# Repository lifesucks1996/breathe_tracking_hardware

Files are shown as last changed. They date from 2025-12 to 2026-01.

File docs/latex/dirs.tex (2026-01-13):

\doxysection{Directories}
\begin{DoxyCompactList}
\item \contentsline{section}{Hola\+Mundo\+IBeacon }{\pageref{dir_2c5f92dce44fa62186c079fa2c237f16}}{}
\begin{DoxyCompactList}
\item \contentsline{section}{Emisora\+BLE.\+h }{\pageref{_emisora_b_l_e_8h}}{}
\item \contentsline{section}{LED.\+h }{\pageref{_l_e_d_8h}}{}
\item \contentsline{section}{Medidor.\+h }{\pageref{_medidor_8h}}{}
\item \contentsline{section}{Publicador.\+h }{\pageref{_publicador_8h}}{}
\item \contentsline{section}{Puerto\+Serie.\+h }{\pageref{_puerto_serie_8h}}{}
\item \contentsline{section}{Servicio\+En\+Emisora.\+h }{\pageref{_servicio_en_emisora_8h}}{}
\end{DoxyCompactList}
\item \contentsline{section}{src }{\pageref{dir_68267d1309a1af8e8297ef4c3efbcdba}}{}
\begin{DoxyCompactList}
\item \contentsline{section}{Hola\+Mundo\+IBeacon }{\pageref{dir_2c5f92dce44fa62186c079fa2c237f16}}{}
\begin{DoxyCompactList}
\item \contentsline{section}{Emisora\+BLE.\+h }{\pageref{_emisora_b_l_e_8h}}{}
\item \contentsline{section}{LED.\+h }{\pageref{_l_e_d_8h}}{}
\item \contentsline{section}{Medidor.\+h }{\pageref{_medidor_8h}}{}
\item \contentsline{section}{Publicador.\+h }{\pageref{_publicador_8h}}{}
\item \contentsline{section}{Puerto\+Serie.\+h }{\pageref{_puerto_serie_8h}}{}
\item \contentsline{section}{Servicio\+En\+Emisora.\+h }{\pageref{_servicio_en_emisora_8h}}{}
\end{DoxyCompactList}
\end{DoxyCompactList}
\end{DoxyCompactList}

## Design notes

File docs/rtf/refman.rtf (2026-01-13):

Breathe Traking

AUTHOR
Version 1.0

Table of Contents

Table of contents

Directory Hierarchy
Directories

HolaMundoIBeacon pagenum
EmisoraBLE.h pagenum
LED.h pagenum
Medidor.h pagenum
Publicador.h pagenum
PuertoSerie.h pagenum
ServicioEnEmisora.h pagenum

src pagenum
HolaMundoIBeacon pagenum
EmisoraBLE.h pagenum
LED.h pagenum
Medidor.h pagenum
Publicador.h pagenum
PuertoSerie.h pagenum
ServicioEnEmisora.h pagenum

Class Index
Class List
Here are the classes, structs, unions and interfaces with brief descriptions:
ServicioEnEmisora::Caracteristica (Representa una Característica GATT dentro de un servicio ) pagenum
EmisoraBLE (Clase que abstrae las funciones de Bluefruit para actuar como periférico BLE ) pagenum
LED (Clase para gestionar un diodo LED conectado a un pin GPIO ) pagenum
Medidor (Se encarga de la adquisición y procesamiento de datos ambientales ) pagenum
Publicador (Gestiona la lógica de empaquetado y emisión de datos de sensores ) pagenum
PuertoSerie (Clase de abstracción para la comunicación serie ) pagenum
ServicioEnEmisora (Clase que representa un Servicio GATT de Bluetooth ) pagenum

File Index
File List
Here is a list of all files with brief descriptions:
src/HolaMundoIBeacon/EmisoraBLE.h (Clase para gestionar la publicidad y conexión de una emisora Bluetooth Low Energy (BLE) ) pagenum
src/HolaMundoIBeacon/LED.h (Clase para el control de un LED y funciones auxiliares de tiempo ) pagenum
src/HolaMundoIBeacon/Medidor.h (Clase para la gestión de sensores analógicos y simulados ) pagenum
src/HolaMundoIBeacon/Publicador.h (Clase para la publicación de mediciones ambientales mediante beacons BLE ) pagenum
src/HolaMundoIBeacon/PuertoSerie.h (Clase para gestionar la comunicación serie del microcontrolador ) pagenum
src/HolaMundoIBeacon/ServicioEnEmisora.h (Gestión de Servicios y Características GATT para BLE ) pagenum

Directory Documentation
src/HolaMundoIBeacon Directory Reference
AAAAAAABQHAAAAAAABQHFiles
file EmisoraBLE.h
Clase para gestionar la publicidad y conexión de una emisora Bluetooth Low Energy (BLE).
file LED.h
Clase para el control de un LED y funciones auxiliares de tiempo.
file Medidor.h
Clase para la gestión de sensores analógicos y simulados.
file Publicador.h
Clase para la publicación de mediciones ambientales mediante beacons BLE.
file PuertoSerie.h
Clase para gestionar la comunicación serie del microcontrolador.
file ServicioEnEmisora.h
Gestión de Servicios y Características GATT para BLE.

src Directory Reference
AAAAAAABQIAAAAAAABQIDirectories
directory HolaMundoIBeacon
Class Documentation
ServicioEnEmisora::Caracteristica Class Reference
AAAAAAAAJGAAAAAAAAJG
Representa una Característica GATT dentro de un servicio.
#include <ServicioEnEmisora.h>

Public Member Functions
Caracteristica (const char *nombreCaracteristica_)
Constructor básico de característica.

Caracteristica (const char *nombreCaracteristica_, uint8_t props, SecureMode_t permisoRead, SecureMode_t permisoWrite, uint8_t tam)
Constructor completo de característica.

void asignarPropiedadesPermisosYTamanyoDatos (uint8_t props, SecureMode_t permisoRead, SecureMode_t permisoWrite, uint8_t tam)
Configura las propiedades, permisos y tamaño de la característica.

uint16_t escribirDatos (const char *str)
Escribe datos de forma local en la característica.

uint16_t notificarDatos (const char *str)
Envía una notificación a los clientes suscritos.

void instalarCallbackCaracteristicaEscrita (CallbackCaracteristicaEscrita cb)
Configura el callback de escritura.

void activar ()
Activa la característica para que sea visible por el servicio.

Private Member Functions
void asignarPropiedades (uint8_t props)
void asignarPermisos (SecureMode_t permisoRead, SecureMode_t permisoWrite)
void asignarTamanyoDatos (uint8_t tam)
Private Attributes
uint8_t uuidCaracteristica [16] = { '0','1','2','3','4','5','6','7','8','9','A','B','C','D','E','F' }
BLECharacteristic laCaracteristica

Detailed Description
Representa una Característica GATT dentro de un servicio.
Definition at line 71 of file ServicioEnEmisora.h.

AAAAAAABQEAAAAAAABQEConstructor & Destructor Documentation
ServicioEnEmisora::Caracteristica::Caracteristica (const char * nombreCaracteristica_)
AAAAAAABJGAAAAAAABJG
Constructor básico de característica.

Parameters
nombreCaracteristica_ | UUID de la característica como string.
Definition at line 81 of file ServicioEnEmisora.h. ServicioEnEmisora::Caracteristica::Caracteristica (const char * nombreCaracteristica_, uint8_t props, SecureMode_t permisoRead, SecureMode_t permisoWrite, uint8_t tam)
AAAAAAABKFAAAAAAABKF
Constructor completo de característica.

Parameters
nombreCaracteristica_ | UUID en formato string.
props | Propiedades (Read, Write, Notify...).
permisoRead | Permisos de seguridad para lectura.
permisoWrite | Permisos de seguridad para escritura.
tam | Tamaño máximo de los datos en bytes.
Definition at line 93 of file ServicioEnEmisora.h.
AAAAAAABQFAAAAAAABQFMember Function Documentation
void ServicioEnEmisora::Caracteristica::activar ()
AAAAAAABMQAAAAAAABMQ
Activa la característica para que sea visible por el servicio.
Definition at line 148 of file ServicioEnEmisora.h.
void ServicioEnEmisora::Caracteristica::asignarPermisos (SecureMode_t permisoRead, SecureMode_t permisoWrite)[private]
AAAAAAABKUAAAAAAABKU
Definition at line 105 of file ServicioEnEmisora.h.
void ServicioEnEmisora::Caracteristica::asignarPropiedades (uint8_t props)[private]
AAAAAAABKSAAAAAAABKS
Definition at line 104 of file ServicioEnEmisora.h.
void ServicioEnEmisora::Caracteristica::asignarPropiedadesPermisosYTamanyoDatos (uint8_t props, SecureMode_t permisoRead, SecureMode_t permisoWrite, uint8_t tam)
AAAAAAABKNAAAAAAABKN
Configura las propiedades, permisos y tamaño de la característica.
Definition at line 114 of file ServicioEnEmisora.h.
void ServicioEnEmisora::Caracteristica::asignarTamanyoDatos (uint8_t tam)[private]
AAAAAAABKYAAAAAAABKY
Definition at line 108 of file ServicioEnEmisora.h.
uint16_t ServicioEnEmisora::Caracteristica::escribirDatos (const char * str)
AAAAAAABLTAAAAAAABLT
Escribe datos de forma local en la característica.

Parameters
str | Cadena a escribir.
Returns Número de bytes escritos.
Definition at line 128 of file ServicioEnEmisora.h.
void ServicioEnEmisora::Caracteristica::instalarCallbackCaracteristicaEscrita (CallbackCaracteristicaEscrita cb)
AAAAAAABMIAAAAAAABMI
Configura el callback de escritura.

Parameters
cb | Función a ejecutar cuando un cliente escribe datos.
Definition at line 141 of file ServicioEnEmisora.h. uint16_t ServicioEnEmisora::Caracteristica::notificarDatos (const char * str)
AAAAAAABMBAAAAAAABMB
Envía una notificación a los clientes suscritos.

Parameters
str | Datos a notificar.
Returns Resultado de la operación de notificación.
Definition at line 135 of file ServicioEnEmisora.h.

AAAAAAABQGAAAAAAABQGMember Data Documentation
BLECharacteristic ServicioEnEmisora::Caracteristica::laCaracteristica[private]
AAAAAAABJLAAAAAAABJL
Definition at line 74 of file ServicioEnEmisora.h.
uint8_t ServicioEnEmisora::Caracteristica::uuidCaracteristica[16] = { '0','1','2','3','4','5','6','7','8','9','A','B','C','D','E','F' }[private]
AAAAAAABJJAAAAAAABJJ
Definition at line 73 of file ServicioEnEmisora.h.

The documentation for this class was generated from the following file:
src/HolaMundoIBeacon/ServicioEnEmisora.h

EmisoraBLE Class Reference
AAAAAAAAAWAAAAAAAAAW
Clase que abstrae las funciones de Bluefruit para actuar como periférico BLE.
#include <EmisoraBLE.h>

Public Types
using CallbackConexionEstablecida = void ( uint16_t connHandle )
Alias para el callback de conexión establecida.

using CallbackConexionTerminada = void ( uint16_t connHandle, uint8_t reason)
Alias para el callback de conexión terminada.

Public Member Functions
EmisoraBLE (const char *nombreEmisora_, const uint16_t fabricanteID_, const int8_t txPower_)
Constructor de la clase EmisoraBLE.

void encenderEmisora ()
Inicializa el hardware Bluefruit y detiene anuncios previos.

void encenderEmisora (CallbackConexionEstablecida cbce, CallbackConexionTerminada cbct)
Enciende la emisora y configura los callbacks de conexión.

void detenerAnuncio ()
Detiene la publicidad (advertising) si está activa.

bool estaAnunciando ()
Comprueba si la emisora está emitiendo anuncios actualmente.

void emitirAnuncioIBeacon (uint8_t *beaconUUID, int16_t major, int16_t minor, uint8_t rssi)
Configura y emite un anuncio estándar iBeacon.

void emitirAnuncioIBeaconLibre (const char *carga, const uint8_t tamanyoCarga)
Emite un anuncio iBeacon con una carga de datos personalizada.

void emitirDatosMultiples (const uint8_t *datos, const uint8_t tamanyoDatos)
Emite datos múltiples en la carga de fabricante.

bool anyadirServicio (ServicioEnEmisora &servicio)
Añade un servicio a la emisora.

bool anyadirServicioConSusCaracteristicas (ServicioEnEmisora &servicio)
Añade un servicio y sus características.

template<typename ... T> bool anyadirServicioConSusCaracteristicas (ServicioEnEmisora &servicio, ServicioEnEmisora::Caracteristica &caracteristica, T &... restoCaracteristicas)
Template recursivo para añadir un servicio con múltiples características.

template<typename ... T> bool anyadirServicioConSusCaracteristicasYActivar (ServicioEnEmisora &servicio, T &... restoCaracteristicas)
Template para añadir servicio, características y activar el servicio.

void instalarCallbackConexionEstablecida (CallbackConexionEstablecida cb)
Instala el callback para conexiones establecidas.

void instalarCallbackConexionTerminada (CallbackConexionTerminada cb)
Instala el callback para desconexiones.

BLEConnection * getConexion (uint16_t connHandle)
Obtiene un puntero al objeto de conexión a partir de su handle.

Private Attributes
const char * nombreEmisora
Nombre que se mostrará en el escaneo BLE.

const uint16_t fabricanteID
ID del fabricante (Company ID) para anuncios.

const int8_t txPower
Potencia de transmisión en dBm.

Detailed Description
Clase que abstrae las funciones de Bluefruit para actuar como periférico BLE.

• ermite emitir anuncios tipo iBeacon, emitir datos de sensores personalizados y gestionar servicios y características de forma dinámica.

Definition at line 19 of file EmisoraBLE.h.

AAAAAAABPKAAAAAAABPKMember Typedef Documentation
using EmisoraBLE::CallbackConexionEstablecida = void ( uint16_t connHandle )
AAAAAAAABOAAAAAAAABO
Alias para el callback de conexión establecida.

Parameters
connHandle | Identificador de la conexión.
Definition at line 32 of file EmisoraBLE.h. using EmisoraBLE::CallbackConexionTerminada = void ( uint16_t connHandle, uint8_t reason)
AAAAAAAABWAAAAAAAABW
Alias para el callback de conexión terminada.

Parameters
connHandle | Identificador de la conexión.
reason | Código de razón de la desconexión.
Definition at line 39 of file EmisoraBLE.h.
AAAAAAABPLAAAAAAABPLConstructor & Destructor Documentation
EmisoraBLE::EmisoraBLE (const char * nombreEmisora_, const uint16_t fabricanteID_, const int8_t txPower_)
AAAAAAAAAXAAAAAAAAAX
Constructor de la clase EmisoraBLE.

Parameters
nombreEmisora_ | Nombre de la emisora.
fabricanteID_ | ID de fabricante (ej. 0x004c para Apple).
txPower_ | Potencia de emisión.
Definition at line 47 of file EmisoraBLE.h.
AAAAAAABPMAAAAAAABPMMember Function Documentation
bool EmisoraBLE::anyadirServicio (ServicioEnEmisora & servicio)
AAAAAAAAIBAAAAAAAAIB
Añade un servicio a la emisora.

Parameters
servicio | Referencia al objeto ServicioEnEmisora.
Returns true si se añadió correctamente.
Definition at line 190 of file EmisoraBLE.h.
bool EmisoraBLE::anyadirServicioConSusCaracteristicas (ServicioEnEmisora & servicio)
AAAAAAAAIQAAAAAAAAIQ
Añade un servicio y sus características.

Parameters
servicio | Referencia al servicio.
Returns true si tuvo éxito.
Definition at line 203 of file EmisoraBLE.h.
template<typename ... T> bool EmisoraBLE::anyadirServicioConSusCaracteristicas (ServicioEnEmisora & servicio, ServicioEnEmisora::Caracteristica & caracteristica, T &... restoCaracteristicas)
AAAAAAAAJEAAAAAAAAJE
Template recursivo para añadir un servicio con múltiples características.

Template Parameters
T | Tipos de las características restantes.
Parameters servicio | Referencia al servicio.
caracteristica | Primera característica a añadir.
restoCaracteristicas | Pack de parámetros con las demás características.
Returns true si tuvo éxito.
Definition at line 216 of file EmisoraBLE.h.
template<typename ... T> bool EmisoraBLE::anyadirServicioConSusCaracteristicasYActivar (ServicioEnEmisora & servicio, T &... restoCaracteristicas)
AAAAAAAAJWAAAAAAAAJW
Template para añadir servicio, características y activar el servicio.

Template Parameters
T | Tipos de las características.
Parameters servicio | Referencia al servicio.
restoCaracteristicas | Pack de características.
Returns true si tuvo éxito.
Definition at line 231 of file EmisoraBLE.h.
void EmisoraBLE::detenerAnuncio ()
AAAAAAAADPAAAAAAAADP
Detiene la publicidad (advertising) si está activa.
Definition at line 79 of file EmisoraBLE.h.
void EmisoraBLE::emitirAnuncioIBeacon (uint8_t * beaconUUID, int16_t major, int16_t minor, uint8_t rssi)
AAAAAAAAEMAAAAAAAAEM
Configura y emite un anuncio estándar iBeacon.

Parameters
beaconUUID | Puntero al array de 16 bytes del UUID.
major | Valor Major del iBeacon.
minor | Valor Minor del iBeacon.
rssi | Valor de RSSI calibrado a 1 metro.
Definition at line 100 of file EmisoraBLE.h. void EmisoraBLE::emitirAnuncioIBeaconLibre (const char * carga, const uint8_t tamanyoCarga)
AAAAAAAAFJAAAAAAAAFJ
Emite un anuncio iBeacon con una carga de datos personalizada.

Parameters
carga | Puntero a los datos (máximo 21 bytes).
tamanyoCarga | Tamaño de los datos a emitir.
Definition at line 122 of file EmisoraBLE.h. void EmisoraBLE::emitirDatosMultiples (const uint8_t * datos, const uint8_t tamanyoDatos)
AAAAAAAAGVAAAAAAAAGV
Emite datos múltiples en la carga de fabricante.
Útil para enviar tramas de sensores empaquetadas.
Parameters
datos | Puntero a los datos.
tamanyoDatos | Longitud de los datos.
Definition at line 159 of file EmisoraBLE.h. void EmisoraBLE::encenderEmisora ()
AAAAAAAACRAAAAAAAACR
Inicializa el hardware Bluefruit y detiene anuncios previos.
Definition at line 59 of file EmisoraBLE.h.
void EmisoraBLE::encenderEmisora (CallbackConexionEstablecida cbce, CallbackConexionTerminada cbct)
AAAAAAAADCAAAAAAAADC
Enciende la emisora y configura los callbacks de conexión.

Parameters
cbce | Callback para cuando se establece una conexión.
cbct | Callback para cuando se pierde una conexión.
Definition at line 69 of file EmisoraBLE.h. bool EmisoraBLE::estaAnunciando ()
AAAAAAAAEAAAAAAAAAEA
Comprueba si la emisora está emitiendo anuncios actualmente.

Returns
true si está anunciando, false en caso contrario.
Definition at line 89 of file EmisoraBLE.h.
BLEConnection * EmisoraBLE::getConexion (uint16_t connHandle)
AAAAAAAALAAAAAAAAALA
Obtiene un puntero al objeto de conexión a partir de su handle.

Parameters
connHandle | Identificador de la conexión.
Returns Puntero a BLEConnection.
Definition at line 259 of file EmisoraBLE.h.
void EmisoraBLE::instalarCallbackConexionEstablecida (CallbackConexionEstablecida cb)
AAAAAAAADGAAAAAAAADG
Instala el callback para conexiones establecidas.

Parameters
cb | Función callback.
Definition at line 242 of file EmisoraBLE.h. void EmisoraBLE::instalarCallbackConexionTerminada (CallbackConexionTerminada cb)
AAAAAAAADIAAAAAAAADI
Instala el callback para desconexiones.

Parameters
cb | Función callback.
Definition at line 250 of file EmisoraBLE.h.
AAAAAAABPNAAAAAAABPNMember Data Documentation
const uint16_t EmisoraBLE::fabricanteID[private]
AAAAAAAABDAAAAAAAABD
ID del fabricante (Company ID) para anuncios.
Definition at line 23 of file EmisoraBLE.h.
const char* EmisoraBLE::nombreEmisora[private]
AAAAAAAABBAAAAAAAABB
Nombre que se mostrará en el escaneo BLE.
Definition at line 22 of file EmisoraBLE.h.
const int8_t EmisoraBLE::txPower[private]
AAAAAAAABFAAAAAAAABF
Potencia de transmisión en dBm.
Definition at line 24 of file EmisoraBLE.h.

The documentation for this class was generated from the following file:
src/HolaMundoIBeacon/EmisoraBLE.h

LED Class Reference
AAAAAAAAMKAAAAAAAAMK
Clase para gestionar un diodo LED conectado a un pin GPIO.
#include <LED.h>

Public Member Functions
LED (int numero)
Constructor de la clase LED.

void encender ()
Enciende el LED.

void apagar ()
Apaga el LED.

void alternar ()
Cambia el estado actual del LED.

void brillar (long tiempo)
Enciende el LED durante un tiempo y luego lo apaga.

Private Attributes
int numeroLED
Número del pin GPIO al que está conectado el LED.

bool encendido
Estado interno del LED (true = encendido, false = apagado).

Detailed Description
Clase para gestionar un diodo LED conectado a un pin GPIO.
Permite realizar operaciones básicas como encender, apagar, alternar el estado o realizar un parpadeo (brillar).
Definition at line 26 of file LED.h.

AAAAAAABPOAAAAAAABPOConstructor & Destructor Documentation
LED::LED (int numero)
AAAAAAAAMLAAAAAAAAML
Constructor de la clase LED.

Parameters
numero | Número del pin donde se conecta el LED.
Configura el pin como salida (OUTPUT) y asegura que el LED comience en estado apagado. Definition at line 39 of file LED.h.
AAAAAAABPPAAAAAAABPPMember Function Documentation
void LED::alternar ()
AAAAAAAAOGAAAAAAAAOG
Cambia el estado actual del LED.
Si el LED está encendido lo apaga, y viceversa.
Definition at line 68 of file LED.h.
void LED::apagar ()
AAAAAAAANFAAAAAAAANF
Apaga el LED.
Pone el pin en nivel bajo (LOW) y actualiza el estado interno.
Definition at line 59 of file LED.h.
void LED::brillar (long tiempo)
AAAAAAAAOUAAAAAAAAOU
Enciende el LED durante un tiempo y luego lo apaga.

Parameters
tiempo | Duración del encendido en milisegundos.
Esta función es bloqueante, ya que utiliza la función esperar(). Definition at line 81 of file LED.h. void LED::encender ()
AAAAAAAANNAAAAAAAANN
Enciende el LED.
Pone el pin en nivel alto (HIGH) y actualiza el estado interno.
Definition at line 50 of file LED.h.

AAAAAAABPQAAAAAAABPQMember Data Documentation
bool LED::encendido[private]
AAAAAAAAMQAAAAAAAAMQ
Estado interno del LED (true = encendido, false = apagado).
Definition at line 29 of file LED.h.
int LED::numeroLED[private]
AAAAAAAAMOAAAAAAAAMO
Número del pin GPIO al que está conectado el LED.
Definition at line 28 of file LED.h.

The documentation for this class was generated from the following file:
src/HolaMundoIBeacon/LED.h

Medidor Class Reference
AAAAAAAASYAAAAAAAASY
Se encarga de la adquisición y procesamiento de datos ambientales.
#include <Medidor.h>

Public Member Functions
Medidor ()
Constructor por defecto.

void iniciarMedidor (int nAvg=50)
Calibra el medidor obteniendo el voltaje de referencia inicial.

int medirBateria ()
Calcula el porcentaje de carga de la batería real.

int medirCO2 ()
Obtiene una medida de CO2 de los datos simulados.

int medirTemperatura ()
Obtiene una medida de temperatura de los datos simulados.

float getVrefBase () const
Retorna el voltaje de referencia base calibrado al inicio.

float leerVgas (int nAvg=10)
Lee el voltaje actual en el pin Vgas del sensor de O3.

float medirPPMSimulado ()
Obtiene una medida de Ozono de los datos simulados.

float medirPPM ()
Realiza la medición real de Ozono (O3) en ppm.

Private Member Functions
float leerVolt (int pin, int nAvg=10)
Lee el voltaje de un pin analógico promediando varias muestras.

Private Attributes
float _Vref_base = 0.0f
Valor de calibración inicial de VREF.

Detailed Description
Se encarga de la adquisición y procesamiento de datos ambientales.

• sta clase encapsula tanto las lecturas de los pines analógicos como el procesamiento matemático para convertir voltajes en unidades físicas.

Definition at line 78 of file Medidor.h.

AAAAAAABPRAAAAAAABPRConstructor & Destructor Documentation
Medidor::Medidor ()
AAAAAAAASZAAAAAAAASZ
Constructor por defecto.
Definition at line 102 of file Medidor.h.

AAAAAAABPSAAAAAAABPSMember Function Documentation
float Medidor::getVrefBase () const
AAAAAAAAWNAAAAAAAAWN
Retorna el voltaje de referencia base calibrado al inicio.

Returns
Voltaje en Voltios.
Definition at line 163 of file Medidor.h.
void Medidor::iniciarMedidor (int nAvg = 50)
AAAAAAAAUHAAAAAAAAUH
Calibra el medidor obteniendo el voltaje de referencia inicial.

Parameters
nAvg | Número de muestras para la calibración (por defecto 50).
Definition at line 109 of file Medidor.h. float Medidor::leerVgas (int nAvg = 10)
AAAAAAAAWXAAAAAAAAWX
Lee el voltaje actual en el pin Vgas del sensor de O3.

Parameters
nAvg | Número de muestras para el promedio.
Returns Voltaje en Voltios.
Definition at line 172 of file Medidor.h.
float Medidor::leerVolt (int pin, int nAvg = 10)[private]
AAAAAAAATMAAAAAAAATM
Lee el voltaje de un pin analógico promediando varias muestras.

Parameters
pin | Pin analógico a leer.
nAvg | Número de muestras para el promedio.
Returns Voltaje calculado en Voltios.
Definition at line 89 of file Medidor.h.
int Medidor::medirBateria ()
AAAAAAAAURAAAAAAAAUR
Calcula el porcentaje de carga de la batería real.
Utiliza un divisor de tensión 2:1 en el pin A6.
Returns
Porcentaje de batería (0-100).
Definition at line 118 of file Medidor.h.
int Medidor::medirCO2 ()
AAAAAAAAVTAAAAAAAAVT
Obtiene una medida de CO2 de los datos simulados.

Returns
Valor de CO2 en ppm.
Definition at line 145 of file Medidor.h.
float Medidor::medirPPM ()
AAAAAAAAXTAAAAAAAAXT
Realiza la medición real de Ozono (O3) en ppm.
Calcula la diferencia entre Vgas y Vref, convierte a corriente y aplica las constantes de sensibilidad y corrección (slope/offset).
Returns
Concentración de ozono corregida en ppm.
Definition at line 192 of file Medidor.h.
float Medidor::medirPPMSimulado ()
AAAAAAAAXGAAAAAAAAXG
Obtiene una medida de Ozono de los datos simulados.

Returns
Valor de ozono en ppm (float).
Definition at line 180 of file Medidor.h.
int Medidor::medirTemperatura ()
AAAAAAAAWDAAAAAAAAWD
Obtiene una medida de temperatura de los datos simulados.

Returns
Temperatura (ºC * 10).
Definition at line 154 of file Medidor.h.

AAAAAAABPTAAAAAAABPTMember Data Documentation
float Medidor::_Vref_base = 0.0f[private]
AAAAAAAATDAAAAAAAATD
Valor de calibración inicial de VREF.
Definition at line 81 of file Medidor.h.

The documentation for this class was generated from the following file:
src/HolaMundoIBeacon/Medidor.h

Publicador Class Reference
AAAAAAAAZQAAAAAAAAZQ
Gestiona la lógica de empaquetado y emisión de datos de sensores.
#include <Publicador.h>

Public Types
enum MedicionesID { CO2 = 11, TEMPERATURA = 12, RUIDO = 13 }
Identificadores numéricos para los distintos tipos de sensores.
Public Member Functions
Publicador ()
Constructor de la clase Publicador.

void encenderEmisora ()
Activa el hardware de la emisora BLE.

void publicarCO2 (int16_t valorCO2, uint8_t contador, long tiempoEspera)
Publica una medición de CO2.

void publicarTemperatura (int16_t valorTemperatura, uint8_t contador, long tiempoEspera)
Publica una medición de Temperatura.

Public Attributes
EmisoraBLE laEmisora
Instancia de la emisora BLE configurada para este publicador.

const int RSSI = -53
Valor de RSSI de referencia para el iBeacon.

Private Attributes
uint8_t beaconUUID [16]
UUID del beacon (16 bytes). Representa la identidad de la red de sensores (EPSG-GTI-PROY-3A).

Detailed Description
Gestiona la lógica de empaquetado y emisión de datos de sensores.

• rganiza las lecturas en el formato estándar de iBeacon, utilizando el campo 'Major' para el ID de la medida y un contador, y el campo 'Minor' para el valor de la medición.

Definition at line 21 of file Publicador.h.

AAAAAAABPUAAAAAAABPUMember Enumeration Documentation
enum Publicador::MedicionesID
AAAAAAABBBAAAAAAABBB
Identificadores numéricos para los distintos tipos de sensores.

Enumerator:
CO2AAAAAAABBDAAAAAAABBD | ID para sensores de Dióxido de Carbono.
TEMPERATURAAAAAAAABBFAAAAAAABBF | ID para sensores de Temperatura.
RUIDOAAAAAAABBHAAAAAAABBH | ID para sensores de Ruido ambiental.
Definition at line 53 of file Publicador.h.
AAAAAAABPVAAAAAAABPVConstructor & Destructor Documentation
Publicador::Publicador ()
AAAAAAAAZRAAAAAAAAZR
Constructor de la clase Publicador.

Note
La emisora no se enciende aquí para evitar problemas de inicialización de hardware.
Definition at line 63 of file Publicador.h.

AAAAAAABPWAAAAAAABPWMember Function Documentation
void Publicador::encenderEmisora ()
AAAAAAABBVAAAAAAABBV
Activa el hardware de la emisora BLE.
Definition at line 69 of file Publicador.h.
void Publicador::publicarCO2 (int16_t valorCO2, uint8_t contador, long tiempoEspera)
AAAAAAABCHAAAAAAABCH
Publica una medición de CO2.

Parameters
valorCO2 | Valor de la medición a enviar (se coloca en el campo Minor).
contador | Valor incremental para diferenciar anuncios.
tiempoEspera | Milisegundos que estará activo el anuncio antes de detenerse.
El campo 'Major' se forma combinando el ID del CO2 (8 bits altos) y el contador (8 bits bajos). Definition at line 80 of file Publicador.h. void Publicador::publicarTemperatura (int16_t valorTemperatura, uint8_t contador, long tiempoEspera)
AAAAAAABDGAAAAAAABDG
Publica una medición de Temperatura.

Parameters
valorTemperatura | Valor térmico (se coloca en el campo Minor).
contador | Valor incremental.
tiempoEspera | Duración del anuncio en milisegundos.
Definition at line 104 of file Publicador.h.
AAAAAAABPXAAAAAAABPXMember Data Documentation
uint8_t Publicador::beaconUUID[16][private]
AAAAAAAAZYAAAAAAAAZYInitial value:
= {
'E', 'P', 'S', 'G', '-', 'G', 'T', 'I',
'-', 'P', 'R', 'O', 'Y', '-', '3', 'A'
}
UUID del beacon (16 bytes). Representa la identidad de la red de sensores (EPSG-GTI-PROY-3A).

◦
efinition at line 27 of file Publicador.h.
EmisoraBLE Publicador::laEmisora
AAAAAAABAKAAAAAAABAKInitial value:
{
"rocio",
0x004c,
4
}
Instancia de la emisora BLE configurada para este publicador.
** Nombre: "rocio"
◦ abricante: Apple (0x004c)
◦ otencia: 4 dBm
Definition at line 38 of file Publicador.h.
const int Publicador::RSSI = -53
AAAAAAABASAAAAAAABAS
Valor de RSSI de referencia para el iBeacon.
Definition at line 45 of file Publicador.h.

The documentation for this class was generated from the following file:
src/HolaMundoIBeacon/Publicador.h

PuertoSerie Class Reference
AAAAAAABETAAAAAAABET
Clase de abstracción para la comunicación serie.
#include <PuertoSerie.h>

Public Member Functions
PuertoSerie (long baudios)
Constructor de la clase PuertoSerie.

void esperarDisponible ()
Bloquea la ejecución hasta que el puerto serie esté listo.

template<typename T> void escribir (T mensaje)
Escribe un mensaje de cualquier tipo en el puerto serie.

Detailed Description
Clase de abstracción para la comunicación serie.
• acilita la inicialización del puerto y permite enviar mensajes de forma genérica mediante el uso de plantillas (templates).

Definition at line 19 of file PuertoSerie.h.

AAAAAAABPYAAAAAAABPYConstructor & Destructor Documentation
PuertoSerie::PuertoSerie (long baudios)
AAAAAAABEUAAAAAAABEU
Constructor de la clase PuertoSerie.

Parameters
baudios | Velocidad de transmisión en bits por segundo (ej. 9600, 115200).
Inicia la comunicación serie con la velocidad especificada. Definition at line 28 of file PuertoSerie.h.
AAAAAAABPZAAAAAAABPZMember Function Documentation
template<typename T> void PuertoSerie::escribir (T mensaje)
AAAAAAABGBAAAAAAABGB
Escribe un mensaje de cualquier tipo en el puerto serie.

Template Parameters
T | Tipo de dato del mensaje (int, float, char*, etc.).
Parameters mensaje | El valor o cadena a enviar.
Utiliza una plantilla para delegar la gestión del tipo al método Serial.print() de Arduino. Definition at line 50 of file PuertoSerie.h. void PuertoSerie::esperarDisponible ()
AAAAAAABFNAAAAAAABFN
Bloquea la ejecución hasta que el puerto serie esté listo.
Es útil en placas con USB nativo donde la conexión serie puede tardar unos milisegundos en establecerse tras el arranque.
Definition at line 37 of file PuertoSerie.h.

The documentation for this class was generated from the following file:
src/HolaMundoIBeacon/PuertoSerie.h

ServicioEnEmisora Class Reference
AAAAAAAAICAAAAAAAAIC
Clase que representa un Servicio GATT de Bluetooth.
#include <ServicioEnEmisora.h>

Classes
class CaracteristicaRepresenta una Característica GATT dentro de un servicio.
Public Types
using CallbackCaracteristicaEscrita
Alias para el callback invocado cuando un cliente escribe en una característica.

Public Member Functions
ServicioEnEmisora (const char *nombreServicio_)
Crea un nuevo servicio BLE.

void escribeUUID ()
Muestra el UUID del servicio por el puerto serie.

void anyadirCaracteristica (Caracteristica &car)
Añade una característica a la lista de este servicio.

void activarServicio ()
Activa el servicio y todas sus características asociadas.

operator BLEService & ()
Operador de conversión para compatibilidad con la librería Bluefruit.

Private Attributes
uint8_t uuidServicio [16] = { '0','1','2','3','4','5','6','7','8','9','A','B','C','D','E','F' }
BLEService elServicio
std::vector< Caracteristica * > lasCaracteristicas
Lista de punteros a características vinculadas.

Detailed Description
Clase que representa un Servicio GATT de Bluetooth.
Contiene una colección de características y gestiona su activación.
Definition at line 56 of file ServicioEnEmisora.h.

AAAAAAABQAAAAAAAABQAMember Typedef Documentation
using ServicioEnEmisora::CallbackCaracteristicaEscrita
AAAAAAABIXAAAAAAABIXInitial value:
void ( uint16_t conn_handle,
BLECharacteristic * chr,
uint8_t * data, uint16_t len)
Alias para el callback invocado cuando un cliente escribe en una característica.
Definition at line 63 of file ServicioEnEmisora.h.

AAAAAAABQBAAAAAAABQBConstructor & Destructor Documentation
ServicioEnEmisora::ServicioEnEmisora (const char * nombreServicio_)
AAAAAAABIPAAAAAAABIP
Crea un nuevo servicio BLE.

Parameters
nombreServicio_ | UUID del servicio como string.
Definition at line 166 of file ServicioEnEmisora.h.
AAAAAAABQCAAAAAAABQCMember Function Documentation
void ServicioEnEmisora::activarServicio ()
AAAAAAAAKAAAAAAAAAKA
Activa el servicio y todas sus características asociadas.
Definition at line 190 of file ServicioEnEmisora.h.
void ServicioEnEmisora::anyadirCaracteristica (Caracteristica & car)
AAAAAAAAJJAAAAAAAAJJ
Añade una característica a la lista de este servicio.

Parameters
car | Referencia a la característica.
Definition at line 183 of file ServicioEnEmisora.h. void ServicioEnEmisora::escribeUUID ()
AAAAAAABNTAAAAAAABNT
Muestra el UUID del servicio por el puerto serie.
Definition at line 173 of file ServicioEnEmisora.h.
ServicioEnEmisora::operator BLEService & ()
AAAAAAABOZAAAAAAABOZ
Operador de conversión para compatibilidad con la librería Bluefruit.

Returns
Referencia al objeto BLEService interno.
Definition at line 204 of file ServicioEnEmisora.h.

AAAAAAABQDAAAAAAABQDMember Data Documentation
BLEService ServicioEnEmisora::elServicio[private]
AAAAAAABNCAAAAAAABNC
Definition at line 158 of file ServicioEnEmisora.h.
std::vector< Caracteristica * > ServicioEnEmisora::lasCaracteristicas[private]
AAAAAAABNEAAAAAAABNE
Lista de punteros a características vinculadas.
Definition at line 159 of file ServicioEnEmisora.h.
uint8_t ServicioEnEmisora::uuidServicio[16] = { '0','1','2','3','4','5','6','7','8','9','A','B','C','D','E','F' }[private]
AAAAAAABNAAAAAAAABNA
Definition at line 157 of file ServicioEnEmisora.h.

The documentation for this class was generated from the following file:
src/HolaMundoIBeacon/ServicioEnEmisora.h

File Documentation
src/HolaMundoIBeacon/EmisoraBLE.h File Reference
AAAAAAAAABAAAAAAAAAB
Clase para gestionar la publicidad y conexión de una emisora Bluetooth Low Energy (BLE).
#include "ServicioEnEmisora.h"

Classes
class EmisoraBLEClase que abstrae las funciones de Bluefruit para actuar como periférico BLE.

Detailed Description
Clase para gestionar la publicidad y conexión de una emisora Bluetooth Low Energy (BLE).

Author
Rocio
Date
11/11/2025
Definition in file EmisoraBLE.h.

EmisoraBLE.h
AAAAAAAAAAAAAAAAAAAAGo to the documentation of this file.

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

src/HolaMundoIBeacon/LED.h File Reference
AAAAAAAALIAAAAAAAALI
Clase para el control de un LED y funciones auxiliares de tiempo.
Classes
class LEDClase para gestionar un diodo LED conectado a un pin GPIO.
Functions
void esperar (long tiempo)
Pausa la ejecución del programa durante un tiempo determinado.

Detailed Description
Clase para el control de un LED y funciones auxiliares de tiempo.

Author
Rocio
Date
11/11/2025
Definition in file LED.h.

AAAAAAABPGAAAAAAABPGFunction Documentation
void esperar (long tiempo)
AAAAAAAALZAAAAAAAALZ
Pausa la ejecución del programa durante un tiempo determinado.

Parameters
tiempo | Cantidad de milisegundos a esperar.
Es un envoltorio (wrapper) de la función estándar delay(). Definition at line 16 of file LED.h.
LED.h
AAAAAAAALHAAAAAAAALHGo to the documentation of this file.

AAAAAAAALJAAAAAAAALJ00001 /**
AAAAAAAALKAAAAAAAALK00002 * @file LED.h
AAAAAAAALLAAAAAAAALL00003 * @brief Clase para el control de un LED y funciones auxiliares de tiempo.
AAAAAAAALMAAAAAAAALM00004 * @author Rocio
AAAAAAAALNAAAAAAAALN00005 * @date 11/11/2025
AAAAAAAALOAAAAAAAALO00006 */
AAAAAAAALPAAAAAAAALP00007
AAAAAAAALQAAAAAAAALQ00008 #ifndef LED_H_INCLUIDO
AAAAAAAALRAAAAAAAALR00009 #define LED_H_INCLUIDO
AAAAAAAALSAAAAAAAALS00010
AAAAAAAALTAAAAAAAALT00011 /**
AAAAAAAALUAAAAAAAALU00012 * @brief Pausa la ejecución del programa durante un tiempo determinado.
AAAAAAAALVAAAAAAAALV00013 * @param tiempo Cantidad de milisegundos a esperar.
AAAAAAAALWAAAAAAAALW00014 * @details Es un envoltorio (wrapper) de la función estándar delay().
AAAAAAAALXAAAAAAAALX00015 */
AAAAAAAALYAAAAAAAALY00016 void esperar (long tiempo) {
AAAAAAAAMAAAAAAAAAMA00017 delay (tiempo);
AAAAAAAAMBAAAAAAAAMB00018 }
AAAAAAAAMCAAAAAAAAMC00019
AAAAAAAAMDAAAAAAAAMD00020 /**
AAAAAAAAMEAAAAAAAAME00021 * @class LED
AAAAAAAAMFAAAAAAAAMF00022 * @brief Clase para gestionar un diodo LED conectado a un pin GPIO.
AAAAAAAAMGAAAAAAAAMG00023 * @details Permite realizar operaciones básicas como encender, apagar,
AAAAAAAAMHAAAAAAAAMH00024 * alternar el estado o realizar un parpadeo (brillar).
AAAAAAAAMIAAAAAAAAMI00025 */
AAAAAAAAMJAAAAAAAAMJ00026 class LED {
AAAAAAAAMMAAAAAAAAMM00027 private:
AAAAAAAAMNAAAAAAAAMN00028 int numeroLED; ///< Número del pin GPIO al que está conectado el LED.
AAAAAAAAMPAAAAAAAAMP00029 bool encendido; ///< Estado interno del LED (true = encendido, false = apagado).
AAAAAAAAMRAAAAAAAAMR00030
AAAAAAAAMSAAAAAAAAMS00031 public:
AAAAAAAAMTAAAAAAAAMT00032
AAAAAAAAMUAAAAAAAAMU00033 /**
AAAAAAAAMVAAAAAAAAMV00034 * @brief Constructor de la clase LED.
AAAAAAAAMWAAAAAAAAMW00035 * @param numero Número del pin donde se conecta el LED.
AAAAAAAAMXAAAAAAAAMX00036 * @details Configura el pin como salida (OUTPUT) y asegura que el LED
AAAAAAAAMYAAAAAAAAMY00037 * comience en estado apagado.
AAAAAAAAMZAAAAAAAAMZ00038 */
AAAAAAAANAAAAAAAAANA00039 LED (int numero)
AAAAAAAANBAAAAAAAANB00040 : numeroLED (numero), encendido(false)
AAAAAAAANCAAAAAAAANC00041 {
AAAAAAAANDAAAAAAAAND00042 pinMode(numeroLED, OUTPUT);
AAAAAAAANEAAAAAAAANE00043 apagar ();
AAAAAAAANGAAAAAAAANG00044 }
AAAAAAAANHAAAAAAAANH00045
AAAAAAAANIAAAAAAAANI00046 /**
AAAAAAAANJAAAAAAAANJ00047 * @brief Enciende el LED.
AAAAAAAANKAAAAAAAANK00048 * @details Pone el pin en nivel alto (HIGH) y actualiza el estado interno.
AAAAAAAANLAAAAAAAANL00049 */
AAAAAAAANMAAAAAAAANM00050 void encender () {
AAAAAAAANOAAAAAAAANO00051 digitalWrite(numeroLED, HIGH);
AAAAAAAANPAAAAAAAANP00052 encendido = true;
AAAAAAAANQAAAAAAAANQ00053 }
AAAAAAAANRAAAAAAAANR00054
AAAAAAAANSAAAAAAAANS00055 /**
AAAAAAAANTAAAAAAAANT00056 * @brief Apaga el LED.
AAAAAAAANUAAAAAAAANU00057 * @details Pone el pin en nivel bajo (LOW) y actualiza el estado interno.
AAAAAAAANVAAAAAAAANV00058 */
AAAAAAAANWAAAAAAAANW00059 void apagar () {
AAAAAAAANXAAAAAAAANX00060 digitalWrite(numeroLED, LOW);
AAAAAAAANYAAAAAAAANY00061 encendido = false;
AAAAAAAANZAAAAAAAANZ00062 }
AAAAAAAAOAAAAAAAAAOA00063
AAAAAAAAOBAAAAAAAAOB00064 /**
AAAAAAAAOCAAAAAAAAOC00065 * @brief Cambia el estado actual del LED.
AAAAAAAAODAAAAAAAAOD00066 * @details Si el LED está encendido lo apaga, y viceversa.
AAAAAAAAOEAAAAAAAAOE00067 */
AAAAAAAAOFAAAAAAAAOF00068 void alternar () {
AAAAAAAAOHAAAAAAAAOH00069 if (encendido) {
AAAAAAAAOIAAAAAAAAOI00070 apagar();
AAAAAAAAOJAAAAAAAAOJ00071 } else {
AAAAAAAAOKAAAAAAAAOK00072 encender ();
AAAAAAAAOLAAAAAAAAOL00073 }
AAAAAAAAOMAAAAAAAAOM00074 }
AAAAAAAAONAAAAAAAAON00075
AAAAAAAAOOAAAAAAAAOO00076 /**
AAAAAAAAOPAAAAAAAAOP00077 * @brief Enciende el LED durante un tiempo y luego lo apaga.
AAAAAAAAOQAAAAAAAAOQ00078 * @param tiempo Duración del encendido en milisegundos.
AAAAAAAAORAAAAAAAAOR00079 * @details Esta función es bloqueante, ya que utiliza la función esperar().
AAAAAAAAOSAAAAAAAAOS00080 */
AAAAAAAAOTAAAAAAAAOT00081 void brillar (long tiempo) {
AAAAAAAAOVAAAAAAAAOV00082 encender ();
AAAAAAAAOWAAAAAAAAOW00083 esperar(tiempo);
AAAAAAAAOXAAAAAAAAOX00084 apagar ();
AAAAAAAAOYAAAAAAAAOY00085 }
AAAAAAAAOZAAAAAAAAOZ00086 }; // class
AAAAAAAAPAAAAAAAAAPA00087
AAAAAAAAPBAAAAAAAAPB00088 #endif

src/HolaMundoIBeacon/Medidor.h File Reference
AAAAAAAAPDAAAAAAAAPD
Clase para la gestión de sensores analógicos y simulados.
#include <Arduino.h>

#include <math.h>

Classes
class MedidorSe encarga de la adquisición y procesamiento de datos ambientales.
Macros
#define O3_PIN_VGAS A5

Pin para el voltaje de gas del sensor de ozono.

#define O3_PIN_VREF A4

Pin para el voltaje de referencia del sensor de ozono.

#define O3_VDD 1.20f

Voltaje de alimentación del sensor/ADC (V).

#define O3_ADC_BITS 12

Resolución del ADC para ozono (12 bits).

Variables
const float SENSIBILIDAD_SENSOR = -44.26f
Sensibilidad del sensor electroquímico en nA/ppm.

const float GAIN_TIA = 499.0f
Resistencia de ganancia del amplificador de transimpedancia (TIA) en Ohmios.

const float CORRECCION_SLOPE = 1.0f
Factor de escala para ajuste de ganancia (m').

const float CORRECCION_OFFSET = 0.0f
Desplazamiento para ajuste de línea base (b').

const int O3_SIMULADO [] = {100, 650, 45, 1200, 950, 800, 300}
Array de valores de Ozono simulados (ppm * 1000).

const int NUM_O3_VALORES = sizeof(O3_SIMULADO) / sizeof(O3_SIMULADO[0])
const int CO2_SIMULADO [] = {1400, 1350, 1360, 1280, 1250, 1300, 1450}
Array de valores de CO2 simulados (ppm).

const int NUM_CO2_VALORES = sizeof(CO2_SIMULADO) / sizeof(CO2_SIMULADO[0])
const int TEMP_SIMULADA [] = {320, 345, 366, 389, 335, 368, 353, 360, 400, 320}
Array de temperaturas simuladas (ºC * 10).

const int NUM_TEMP_VALORES = sizeof(TEMP_SIMULADA) / sizeof(TEMP_SIMULADA[0])
const int BAT_SIMULADA [] = {15, 14, 12, 10, 8, 7, 3, 1}
Array de porcentajes de batería simulados.

const int NUM_BAT_VALORES = sizeof(BAT_SIMULADA) / sizeof(BAT_SIMULADA[0])
const float BATT_MAX_VOLTS = 4.20f
Voltaje LiPo al 100%.

const float BATT_MIN_VOLTS = 3.30f
Voltaje LiPo al 0%.

const float VDD = 3.30f
Referencia de voltaje del sistema (V).

const int ADC_BITS = 10
Resolución ADC para batería.

Detailed Description
Clase para la gestión de sensores analógicos y simulados.

Author
Rocio
Date
11/11/2025
Este archivo contiene la lógica para calcular concentraciones de O3 mediante un sensor electroquímico, así como la estimación del nivel de batería y la generación de datos simulados para CO2 y Temperatura.
Definition in file Medidor.h.

AAAAAAABPHAAAAAAABPHMacro Definition Documentation
#define O3_ADC_BITS 12

AAAAAAAAQMAAAAAAAAQM
Resolución del ADC para ozono (12 bits).
Definition at line 31 of file Medidor.h.
#define O3_PIN_VGAS A5

AAAAAAAAPYAAAAAAAAPY
Pin para el voltaje de gas del sensor de ozono.
Definition at line 20 of file Medidor.h.
#define O3_PIN_VREF A4

AAAAAAAAQCAAAAAAAAQC
Pin para el voltaje de referencia del sensor de ozono.
Definition at line 23 of file Medidor.h.
#define O3_VDD 1.20f

AAAAAAAAQHAAAAAAAAQH
Voltaje de alimentación del sensor/ADC (V).
Definition at line 27 of file Medidor.h.

AAAAAAABPIAAAAAAABPIVariable Documentation
const int ADC_BITS = 10
AAAAAAAASPAAAAAAAASP
Resolución ADC para batería.
Definition at line 70 of file Medidor.h.
const int BAT_SIMULADA[] = {15, 14, 12, 10, 8, 7, 3, 1}
AAAAAAAASCAAAAAAAASC
Array de porcentajes de batería simulados.
Definition at line 62 of file Medidor.h.
const float BATT_MAX_VOLTS = 4.20f
AAAAAAAASJAAAAAAAASJ
Voltaje LiPo al 100%.
Definition at line 67 of file Medidor.h.
const float BATT_MIN_VOLTS = 3.30f
AAAAAAAASLAAAAAAAASL
Voltaje LiPo al 0%.
Definition at line 68 of file Medidor.h.
const int CO2_SIMULADO[] = {1400, 1350, 1360, 1280, 1250, 1300, 1450}
AAAAAAAAROAAAAAAAARO
Array de valores de CO2 simulados (ppm).
Definition at line 52 of file Medidor.h.
const float CORRECCION_OFFSET = 0.0f
AAAAAAAARBAAAAAAAARB
Desplazamiento para ajuste de línea base (b').
Definition at line 42 of file Medidor.h.
const float CORRECCION_SLOPE = 1.0f
AAAAAAAAQZAAAAAAAAQZ
Factor de escala para ajuste de ganancia (m').
Definition at line 41 of file Medidor.h.
const float GAIN_TIA = 499.0f
AAAAAAAAQUAAAAAAAAQU
Resistencia de ganancia del amplificador de transimpedancia (TIA) en Ohmios.
Definition at line 37 of file Medidor.h.
const int NUM_BAT_VALORES = sizeof(BAT_SIMULADA) / sizeof(BAT_SIMULADA[0])
AAAAAAAASEAAAAAAAASE
Definition at line 63 of file Medidor.h.
const int NUM_CO2_VALORES = sizeof(CO2_SIMULADO) / sizeof(CO2_SIMULADO[0])
AAAAAAAARQAAAAAAAARQ
Definition at line 53 of file Medidor.h.
const int NUM_O3_VALORES = sizeof(O3_SIMULADO) / sizeof(O3_SIMULADO[0])
AAAAAAAARJAAAAAAAARJ
Definition at line 48 of file Medidor.h.
const int NUM_TEMP_VALORES = sizeof(TEMP_SIMULADA) / sizeof(TEMP_SIMULADA[0])
AAAAAAAARXAAAAAAAARX
Definition at line 58 of file Medidor.h.
const int O3_SIMULADO[] = {100, 650, 45, 1200, 950, 800, 300}
AAAAAAAARHAAAAAAAARH
Array de valores de Ozono simulados (ppm * 1000).
Definition at line 47 of file Medidor.h.
const float SENSIBILIDAD_SENSOR = -44.26f
AAAAAAAAQRAAAAAAAAQR
Sensibilidad del sensor electroquímico en nA/ppm.
Definition at line 35 of file Medidor.h.
const int TEMP_SIMULADA[] = {320, 345, 366, 389, 335, 368, 353, 360, 400, 320}
AAAAAAAARVAAAAAAAARV
Array de temperaturas simuladas (ºC * 10).
Definition at line 57 of file Medidor.h.
const float VDD = 3.30f
AAAAAAAASNAAAAAAAASN
Referencia de voltaje del sistema (V).
Definition at line 69 of file Medidor.h.

Medidor.h
AAAAAAAAPCAAAAAAAAPCGo to the documentation of this file.

AAAAAAAAPEAAAAAAAAPE00001 /**
AAAAAAAAPFAAAAAAAAPF00002 * @file Medidor.h
AAAAAAAAPGAAAAAAAAPG00003 * @brief Clase para la gestión de sensores analógicos y simulados.
AAAAAAAAPHAAAAAAAAPH00004 * @author Rocio
AAAAAAAAPIAAAAAAAAPI00005 * @date 11/11/2025
AAAAAAAAPJAAAAAAAAPJ00006 * @details Este archivo contiene la lógica para calcular concentraciones de O3
AAAAAAAAPKAAAAAAAAPK00007 * mediante un sensor electroquímico, así como la estimación del nivel de batería
AAAAAAAAPLAAAAAAAAPL00008 * y la generación de datos simulados para CO2 y Temperatura.
AAAAAAAAPMAAAAAAAAPM00009 */
AAAAAAAAPNAAAAAAAAPN00010
AAAAAAAAPOAAAAAAAAPO00011 #ifndef MEDIDOR_H_INCLUIDO
AAAAAAAAPPAAAAAAAAPP00012 #define MEDIDOR_H_INCLUIDO
AAAAAAAAPQAAAAAAAAPQ00013
AAAAAAAAPRAAAAAAAAPR00014 #include <Arduino.h>
AAAAAAAAPSAAAAAAAAPS00015 #include <math.h>
AAAAAAAAPTAAAAAAAAPT00016
AAAAAAAAPUAAAAAAAAPU00017 // ===================== CONSTANTES DE CONFIGURACIÓN (O3) =====================
AAAAAAAAPVAAAAAAAAPV00018
AAAAAAAAPWAAAAAAAAPW00019 #ifndef O3_PIN_VGAS
AAAAAAAAPXAAAAAAAAPX00020 #define O3_PIN_VGAS A5 ///< Pin para el voltaje de gas del sensor de ozono.
AAAAAAAAPZAAAAAAAAPZ00021 #endif
AAAAAAAAQAAAAAAAAAQA00022 #ifndef O3_PIN_VREF
AAAAAAAAQBAAAAAAAAQB00023 #define O3_PIN_VREF A4 ///< Pin para el voltaje de referencia del sensor de ozono.
AAAAAAAAQDAAAAAAAAQD00024 #endif
AAAAAAAAQEAAAAAAAAQE00025
AAAAAAAAQFAAAAAAAAQF00026 #ifndef O3_VDD
AAAAAAAAQGAAAAAAAAQG00027 #define O3_VDD 1.20f ///< Voltaje de alimentación del sensor/ADC (V).
AAAAAAAAQIAAAAAAAAQI00028 #endif
AAAAAAAAQJAAAAAAAAQJ00029
AAAAAAAAQKAAAAAAAAQK00030 #ifndef O3_ADC_BITS
AAAAAAAAQLAAAAAAAAQL00031 #define O3_ADC_BITS 12 ///< Resolución del ADC para ozono (12 bits).
AAAAAAAAQNAAAAAAAAQN00032 #endif
AAAAAAAAQOAAAAAAAAQO00033
AAAAAAAAQPAAAAAAAAQP00034 /** @brief Sensibilidad del sensor electroquímico en nA/ppm. */
AAAAAAAAQQAAAAAAAAQQ00035 const float SENSIBILIDAD_SENSOR = -44.26f;
AAAAAAAAQSAAAAAAAAQS00036 /** @brief Resistencia de ganancia del amplificador de transimpedancia (TIA) en Ohmios. */
AAAAAAAAQTAAAAAAAAQT00037 const float GAIN_TIA = 499.0f;
AAAAAAAAQVAAAAAAAAQV00038
AAAAAAAAQWAAAAAAAAQW00039 // ===================== CONSTANTES DE CORRECCIÓN =====================
AAAAAAAAQXAAAAAAAAQX00040
AAAAAAAAQYAAAAAAAAQY00041 const float CORRECCION_SLOPE = 1.0f; ///< Factor de escala para ajuste de ganancia (m').
AAAAAAAARAAAAAAAAARA00042 const float CORRECCION_OFFSET = 0.0f; ///< Desplazamiento para ajuste de línea base (b').
AAAAAAAARCAAAAAAAARC00043
AAAAAAAARDAAAAAAAARD00044 // ===================== DATOS SIMULADOS =====================
AAAAAAAAREAAAAAAAARE00045
AAAAAAAARFAAAAAAAARF00046 /// @brief Array de valores de Ozono simulados (ppm * 1000).
AAAAAAAARGAAAAAAAARG00047 const int O3_SIMULADO[] = {100, 650, 45, 1200, 950, 800, 300};
AAAAAAAARIAAAAAAAARI00048 const int NUM_O3_VALORES = sizeof(O3_SIMULADO) / sizeof(O3_SIMULADO[0]);
AAAAAAAARKAAAAAAAARK00049
AAAAAAAARLAAAAAAAARL00050 /// @brief Array de valores de CO2 simulados (ppm).
AAAAAAAARMAAAAAAAARM00051 //const int CO2_SIMULADO[] = {400, 550, 850, 1000, 1250, 1300, 950};
AAAAAAAARNAAAAAAAARN00052 const int CO2_SIMULADO[] = {1400, 1350, 1360, 1280, 1250, 1300, 1450};
AAAAAAAARPAAAAAAAARP00053 const int NUM_CO2_VALORES = sizeof(CO2_SIMULADO) / sizeof(CO2_SIMULADO[0]);
AAAAAAAARRAAAAAAAARR00054
AAAAAAAARSAAAAAAAARS00055 /// @brief Array de temperaturas simuladas (ºC * 10).
AAAAAAAARTAAAAAAAART00056 //const int TEMP_SIMULADA[] = {220, 245, 266, 289, 235, 68, 353, 360, 400, 320};
AAAAAAAARUAAAAAAAARU00057 const int TEMP_SIMULADA[] = {320, 345, 366, 389, 335, 368, 353, 360, 400, 320};
AAAAAAAARWAAAAAAAARW00058 const int NUM_TEMP_VALORES = sizeof(TEMP_SIMULADA) / sizeof(TEMP_SIMULADA[0]);
AAAAAAAARYAAAAAAAARY00059
AAAAAAAARZAAAAAAAARZ00060 /// @brief Array de porcentajes de batería simulados.
AAAAAAAASAAAAAAAAASA00061 //const int BAT_SIMULADA[] = {98, 87, 80, 75, 50, 30, 15, 77, 63};
AAAAAAAASBAAAAAAAASB00062 const int BAT_SIMULADA[] = {15, 14, 12, 10, 8, 7, 3, 1};
AAAAAAAASDAAAAAAAASD00063 const int NUM_BAT_VALORES = sizeof(BAT_SIMULADA) / sizeof(BAT_SIMULADA[0]);
AAAAAAAASFAAAAAAAASF00064
AAAAAAAASGAAAAAAAASG00065 // ===================== CONSTANTES BATERÍA REAL =====================
AAAAAAAASHAAAAAAAASH00066
AAAAAAAASIAAAAAAAASI00067 const float BATT_MAX_VOLTS = 4.20f; ///< Voltaje LiPo al 100%.
AAAAAAAASKAAAAAAAASK00068 const float BATT_MIN_VOLTS = 3.30f; ///< Voltaje LiPo al 0%.
AAAAAAAASMAAAAAAAASM00069 const float VDD = 3.30f; ///< Referencia de voltaje del sistema (V).
AAAAAAAASOAAAAAAAASO00070 const int ADC_BITS = 10; ///< Resolución ADC para batería.
AAAAAAAASQAAAAAAAASQ00071
AAAAAAAASRAAAAAAAASR00072 /**
AAAAAAAASSAAAAAAAASS00073 * @class Medidor
AAAAAAAASTAAAAAAAAST00074 * @brief Se encarga de la adquisición y procesamiento de datos ambientales.
AAAAAAAASUAAAAAAAASU00075 * * Esta clase encapsula tanto las lecturas de los pines analógicos como
AAAAAAAASVAAAAAAAASV00076 * el procesamiento matemático para convertir voltajes en unidades físicas.
AAAAAAAASWAAAAAAAASW00077 */
AAAAAAAASXAAAAAAAASX00078 class Medidor {
AAAAAAAATAAAAAAAAATA00079
AAAAAAAATBAAAAAAAATB00080 private:
AAAAAAAATCAAAAAAAATC00081 float _Vref_base = 0.0f; ///< Valor de calibración inicial de VREF.
AAAAAAAATEAAAAAAAATE00082
AAAAAAAATFAAAAAAAATF00083 /**
AAAAAAAATGAAAAAAAATG00084 * @brief Lee el voltaje de un pin analógico promediando varias muestras.
AAAAAAAATHAAAAAAAATH00085 * @param pin Pin analógico a leer.
AAAAAAAATIAAAAAAAATI00086 * @param nAvg Número de muestras para el promedio.
AAAAAAAATJAAAAAAAATJ00087 * @return Voltaje calculado en Voltios.
AAAAAAAATKAAAAAAAATK00088 */
AAAAAAAATLAAAAAAAATL00089 float leerVolt(int pin, int nAvg = 10) {
AAAAAAAATNAAAAAAAATN00090 long acc = 0;
AAAAAAAATOAAAAAAAATO00091 for (int i=0; i<nAvg; ++i) { acc += analogRead(pin); delay(2); }
AAAAAAAATPAAAAAAAATP00092 const float raw = (float)acc / nAvg;
AAAAAAAATQAAAAAAAATQ00093 const float fullScale = (float)((1 << O3_ADC_BITS) - 1);
AAAAAAAATRAAAAAAAATR00094 return (raw * O3_VDD) / fullScale;
AAAAAAAATSAAAAAAAATS00095 }
AAAAAAAATTAAAAAAAATT00096
AAAAAAAATUAAAAAAAATU00097 public:
AAAAAAAATVAAAAAAAATV00098
AAAAAAAATWAAAAAAAATW00099 /**
AAAAAAAATXAAAAAAAATX00100 * @brief Constructor por defecto.
AAAAAAAATYAAAAAAAATY00101 */
AAAAAAAATZAAAAAAAATZ00102 Medidor( ) {
AAAAAAAAUAAAAAAAAAUA00103 }
AAAAAAAAUBAAAAAAAAUB00104
AAAAAAAAUCAAAAAAAAUC00105 /**
AAAAAAAAUDAAAAAAAAUD00106 * @brief Calibra el medidor obteniendo el voltaje de referencia inicial.
AAAAAAAAUEAAAAAAAAUE00107 * @param nAvg Número de muestras para la calibración (por defecto 50).
AAAAAAAAUFAAAAAAAAUF00108 */
AAAAAAAAUGAAAAAAAAUG00109 void iniciarMedidor(int nAvg = 50) {
AAAAAAAAUIAAAAAAAAUI00110 _Vref_base = leerVolt(O3_PIN_VREF, nAvg);
AAAAAAAAUJAAAAAAAAUJ00111 }
AAAAAAAAUKAAAAAAAAUK00112
AAAAAAAAULAAAAAAAAUL00113 /**
AAAAAAAAUMAAAAAAAAUM00114 * @brief Calcula el porcentaje de carga de la batería real.
AAAAAAAAUNAAAAAAAAUN00115 * @details Utiliza un divisor de tensión 2:1 en el pin A6.
AAAAAAAAUOAAAAAAAAUO00116 * @return Porcentaje de batería (0-100).
AAAAAAAAUPAAAAAAAAUP00117 */
AAAAAAAAUQAAAAAAAAUQ00118 int medirBateria() {
AAAAAAAAUSAAAAAAAAUS00119 const int nAvg = 10;
AAAAAAAAUTAAAAAAAAUT00120 long rawAcc = 0;
AAAAAAAAUUAAAAAAAAUU00121 for (int i = 0; i < nAvg; ++i) {
AAAAAAAAUVAAAAAAAAUV00122 rawAcc += analogRead(PIN_A6);
AAAAAAAAUWAAAAAAAAUW00123 delay(1);
AAAAAAAAUXAAAAAAAAUX00124 }
AAAAAAAAUYAAAAAAAAUY00125 const float rawAvg = (float)rawAcc / nAvg;
AAAAAAAAUZAAAAAAAAUZ00126 const float fullScale = (float)((1 << ADC_BITS) - 1);
AAAAAAAAVAAAAAAAAAVA00127 float measuredVolts = (rawAvg * VDD) / fullScale;
AAAAAAAAVBAAAAAAAAVB00128
AAAAAAAAVCAAAAAAAAVC00129 // Multiplicar por 2 por el divisor de voltaje del hardware
AAAAAAAAVDAAAAAAAAVD00130 float battVolts = measuredVolts * 2.0f;
AAAAAAAAVEAAAAAAAAVE00131
AAAAAAAAVFAAAAAAAAVF00132 float battRange = BATT_MAX_VOLTS - BATT_MIN_VOLTS;
AAAAAAAAVGAAAAAAAAVG00133 float percent = ((battVolts - BATT_MIN_VOLTS) / battRange) * 100.0f;
AAAAAAAAVHAAAAAAAAVH00134
AAAAAAAAVIAAAAAAAAVI00135 if (percent > 100.0f) percent = 100.0f;
AAAAAAAAVJAAAAAAAAVJ00136 if (percent < 0.0f) percent = 0.0f;
AAAAAAAAVKAAAAAAAAVK00137
AAAAAAAAVLAAAAAAAAVL00138 return (int)percent;
AAAAAAAAVMAAAAAAAAVM00139 }
AAAAAAAAVNAAAAAAAAVN00140
AAAAAAAAVOAAAAAAAAVO00141 /**
AAAAAAAAVPAAAAAAAAVP00142 * @brief Obtiene una medida de CO2 de los datos simulados.
AAAAAAAAVQAAAAAAAAVQ00143 * @return Valor de CO2 en ppm.
AAAAAAAAVRAAAAAAAAVR00144 */
AAAAAAAAVSAAAAAAAAVS00145 int medirCO2() {
AAAAAAAAVUAAAAAAAAVU00146 int indiceAleatorio = random(0, NUM_CO2_VALORES);
AAAAAAAAVVAAAAAAAAVV00147 return CO2_SIMULADO[indiceAleatorio];
AAAAAAAAVWAAAAAAAAVW00148 }
AAAAAAAAVXAAAAAAAAVX00149
AAAAAAAAVYAAAAAAAAVY00150 /**
AAAAAAAAVZAAAAAAAAVZ00151 * @brief Obtiene una medida de temperatura de los datos simulados.
AAAAAAAAWAAAAAAAAAWA00152 * @return Temperatura (ºC * 10).
AAAAAAAAWBAAAAAAAAWB00153 */
AAAAAAAAWCAAAAAAAAWC00154 int medirTemperatura() {
AAAAAAAAWEAAAAAAAAWE00155 int indiceAleatorio = random(0, NUM_TEMP_VALORES);
AAAAAAAAWFAAAAAAAAWF00156 return TEMP_SIMULADA[indiceAleatorio];
AAAAAAAAWGAAAAAAAAWG00157 }
AAAAAAAAWHAAAAAAAAWH00158
AAAAAAAAWIAAAAAAAAWI00159 /**
AAAAAAAAWJAAAAAAAAWJ00160 * @brief Retorna el voltaje de referencia base calibrado al inicio.
AAAAAAAAWKAAAAAAAAWK00161 * @return Voltaje en Voltios.
AAAAAAAAWLAAAAAAAAWL00162 */
AAAAAAAAWMAAAAAAAAWM00163 float getVrefBase() const {
AAAAAAAAWOAAAAAAAAWO00164 return _Vref_base;
AAAAAAAAWPAAAAAAAAWP00165 }
AAAAAAAAWQAAAAAAAAWQ00166
AAAAAAAAWRAAAAAAAAWR00167 /**
AAAAAAAAWSAAAAAAAAWS00168 * @brief Lee el voltaje actual en el pin Vgas del sensor de O3.
AAAAAAAAWTAAAAAAAAWT00169 * @param nAvg Número de muestras para el promedio.
AAAAAAAAWUAAAAAAAAWU00170 * @return Voltaje en Voltios.
AAAAAAAAWVAAAAAAAAWV00171 */
AAAAAAAAWWAAAAAAAAWW00172 float leerVgas(int nAvg = 10) {
AAAAAAAAWYAAAAAAAAWY00173 return leerVolt(O3_PIN_VGAS, nAvg);
AAAAAAAAWZAAAAAAAAWZ00174 }
AAAAAAAAXAAAAAAAAAXA00175
AAAAAAAAXBAAAAAAAAXB00176 /**
AAAAAAAAXCAAAAAAAAXC00177 * @brief Obtiene una medida de Ozono de los datos simulados.
AAAAAAAAXDAAAAAAAAXD00178 * @return Valor de ozono en ppm (float).
AAAAAAAAXEAAAAAAAAXE00179 */
AAAAAAAAXFAAAAAAAAXF00180 float medirPPMSimulado() {
AAAAAAAAXHAAAAAAAAXH00181 int indiceAleatorio = random(0, NUM_O3_VALORES);
AAAAAAAAXIAAAAAAAAXI00182 float valorSimuladoRaw = (float)O3_SIMULADO[indiceAleatorio];
AAAAAAAAXJAAAAAAAAXJ00183 return valorSimuladoRaw / 1000.0f;
AAAAAAAAXKAAAAAAAAXK00184 }
AAAAAAAAXLAAAAAAAAXL00185
AAAAAAAAXMAAAAAAAAXM00186 /**
AAAAAAAAXNAAAAAAAAXN00187 * @brief Realiza la medición real de Ozono (O3) en ppm.
AAAAAAAAXOAAAAAAAAXO00188 * @details Calcula la diferencia entre Vgas y Vref, convierte a corriente y
AAAAAAAAXPAAAAAAAAXP00189 * aplica las constantes de sensibilidad y corrección (slope/offset).
AAAAAAAAXQAAAAAAAAXQ00190 * @return Concentración de ozono corregida en ppm.
AAAAAAAAXRAAAAAAAAXR00191 */
AAAAAAAAXSAAAAAAAAXS00192 float medirPPM() {
AAAAAAAAXUAAAAAAAAXU00193 float Vg = leerVolt(O3_PIN_VGAS, 10);
AAAAAAAAXVAAAAAAAAXV00194 float deltaV = Vg - _Vref_base;
AAAAAAAAXWAAAAAAAAXW00195
AAAAAAAAXXAAAAAAAAXX00196 float denominador = GAIN_TIA * SENSIBILIDAD_SENSOR * 1e-6f;
AAAAAAAAXYAAAAAAAAXY00197
AAAAAAAAXZAAAAAAAAXZ00198 float ppm_bruto = 0.0f;
AAAAAAAAYAAAAAAAAAYA00199 if (denominador != 0.0f) {
AAAAAAAAYBAAAAAAAAYB00200 ppm_bruto = deltaV / denominador;
AAAAAAAAYCAAAAAAAAYC00201 }
AAAAAAAAYDAAAAAAAAYD00202
AAAAAAAAYEAAAAAAAAYE00203 ppm_bruto = fabsf(ppm_bruto);
AAAAAAAAYFAAAAAAAAYF00204
AAAAAAAAYGAAAAAAAAYG00205 // Ajuste lineal final
AAAAAAAAYHAAAAAAAAYH00206 float ppm_corregido = (ppm_bruto * CORRECCION_SLOPE) + CORRECCION_OFFSET;
AAAAAAAAYIAAAAAAAAYI00207
AAAAAAAAYJAAAAAAAAYJ00208 if (ppm_corregido < 0.0f) {
AAAAAAAAYKAAAAAAAAYK00209 ppm_corregido = 0.0f;
AAAAAAAAYLAAAAAAAAYL00210 }
AAAAAAAAYMAAAAAAAAYM00211
AAAAAAAAYNAAAAAAAAYN00212 return ppm_corregido;
AAAAAAAAYOAAAAAAAAYO00213 }
AAAAAAAAYPAAAAAAAAYP00214
AAAAAAAAYQAAAAAAAAYQ00215 }; // class
AAAAAAAAYRAAAAAAAAYR00216
AAAAAAAAYSAAAAAAAAYS00217 #endif

src/HolaMundoIBeacon/Publicador.h File Reference
AAAAAAAAYUAAAAAAAAYU
Clase para la publicación de mediciones ambientales mediante beacons BLE.
Classes
class PublicadorGestiona la lógica de empaquetado y emisión de datos de sensores.

Detailed Description
Clase para la publicación de mediciones ambientales mediante beacons BLE.

Author
Rocio
Date
11/11/2025
Esta clase actúa como un nivel de abstracción sobre EmisoraBLE, facilitando el envío de datos específicos (CO2, Temperatura) formateados como anuncios iBeacon.
Definition in file Publicador.h.

Publicador.h
AAAAAAAAYTAAAAAAAAYTGo to the documentation of this file.

AAAAAAAAYVAAAAAAAAYV00001 /**
AAAAAAAAYWAAAAAAAAYW00002 * @file Publicador.h
AAAAAAAAYXAAAAAAAAYX00003 * @brief Clase para la publicación de mediciones ambientales mediante beacons BLE.
AAAAAAAAYYAAAAAAAAYY00004 * @author Rocio
AAAAAAAAYZAAAAAAAAYZ00005 * @date 11/11/2025
AAAAAAAAZAAAAAAAAAZA00006 * @details Esta clase actúa como un nivel de abstracción sobre EmisoraBLE,
AAAAAAAAZBAAAAAAAAZB00007 * facilitando el envío de datos específicos (CO2, Temperatura) formateados
AAAAAAAAZCAAAAAAAAZC00008 * como anuncios iBeacon.
AAAAAAAAZDAAAAAAAAZD00009 */
AAAAAAAAZEAAAAAAAAZE00010
AAAAAAAAZFAAAAAAAAZF00011 #ifndef PUBLICADOR_H_INCLUIDO
AAAAAAAAZGAAAAAAAAZG00012 #define PUBLICADOR_H_INCLUIDO
AAAAAAAAZHAAAAAAAAZH00013
AAAAAAAAZIAAAAAAAAZI00014 /**
AAAAAAAAZJAAAAAAAAZJ00015 * @class Publicador
AAAAAAAAZKAAAAAAAAZK00016 * @brief Gestiona la lógica de empaquetado y emisión de datos de sensores.
AAAAAAAAZLAAAAAAAAZL00017 * * Organiza las lecturas en el formato estándar de iBeacon, utilizando el
AAAAAAAAZMAAAAAAAAZM00018 * campo 'Major' para el ID de la medida y un contador, y el campo 'Minor'
AAAAAAAAZNAAAAAAAAZN00019 * para el valor de la medición.
AAAAAAAAZOAAAAAAAAZO00020 */
AAAAAAAAZPAAAAAAAAZP00021 class Publicador {
AAAAAAAAZSAAAAAAAAZS00022
AAAAAAAAZTAAAAAAAAZT00023 private:
AAAAAAAAZUAAAAAAAAZU00024 /** * @brief UUID del beacon (16 bytes).
AAAAAAAAZVAAAAAAAAZV00025 * Representa la identidad de la red de sensores (EPSG-GTI-PROY-3A).
AAAAAAAAZWAAAAAAAAZW00026 */
AAAAAAAAZXAAAAAAAAZX00027 uint8_t beaconUUID[16] = {
AAAAAAAAZZAAAAAAAAZZ00028 'E', 'P', 'S', 'G', '-', 'G', 'T', 'I',
AAAAAAABAAAAAAAAABAA00029 '-', 'P', 'R', 'O', 'Y', '-', '3', 'A'
AAAAAAABABAAAAAAABAB00030 };
AAAAAAABACAAAAAAABAC00031
AAAAAAABADAAAAAAABAD00032 public:
AAAAAAABAEAAAAAAABAE00033 /** * @brief Instancia de la emisora BLE configurada para este publicador.
AAAAAAABAFAAAAAAABAF00034 * * Nombre: "rocio"
AAAAAAABAGAAAAAAABAG00035 * * Fabricante: Apple (0x004c)
AAAAAAABAHAAAAAAABAH00036 * * Potencia: 4 dBm
AAAAAAABAIAAAAAAABAI00037 */
AAAAAAABAJAAAAAAABAJ00038 EmisoraBLE laEmisora {
AAAAAAABALAAAAAAABAL00039 "rocio",
AAAAAAABAMAAAAAAABAM00040 0x004c,
AAAAAAABANAAAAAAABAN00041 4
AAAAAAABAOAAAAAAABAO00042 };
AAAAAAABAPAAAAAAABAP00043
AAAAAAABAQAAAAAAABAQ00044 /** @brief Valor de RSSI de referencia para el iBeacon. */
AAAAAAABARAAAAAAABAR00045 const int RSSI = -53;
AAAAAAABATAAAAAAABAT00046
AAAAAAABAUAAAAAAABAU00047 public:
AAAAAAABAVAAAAAAABAV00048
AAAAAAABAWAAAAAAABAW00049 /**
AAAAAAABAXAAAAAAABAX00050 * @enum MedicionesID
AAAAAAABAYAAAAAAABAY00051 * @brief Identificadores numéricos para los distintos tipos de sensores.
AAAAAAABAZAAAAAAABAZ00052 */
AAAAAAABBAAAAAAAABBA00053 enum MedicionesID {
AAAAAAABBCAAAAAAABBC00054 CO2 = 11, ///< ID para sensores de Dióxido de Carbono.
AAAAAAABBEAAAAAAABBE00055 TEMPERATURA = 12, ///< ID para sensores de Temperatura.
AAAAAAABBGAAAAAAABBG00056 RUIDO = 13 ///< ID para sensores de Ruido ambiental.
AAAAAAABBIAAAAAAABBI00057 };
AAAAAAABBJAAAAAAABBJ00058
AAAAAAABBKAAAAAAABBK00059 /**
AAAAAAABBLAAAAAAABBL00060 * @brief Constructor de la clase Publicador.
AAAAAAABBMAAAAAAABBM00061 * @note La emisora no se enciende aquí para evitar problemas de inicialización de hardware.
AAAAAAABBNAAAAAAABBN00062 */
AAAAAAABBOAAAAAAABBO00063 Publicador( ) {
AAAAAAABBPAAAAAAABBP00064 }
AAAAAAABBQAAAAAAABBQ00065
AAAAAAABBRAAAAAAABBR00066 /**
AAAAAAABBSAAAAAAABBS00067 * @brief Activa el hardware de la emisora BLE.
AAAAAAABBTAAAAAAABBT00068 */
AAAAAAABBUAAAAAAABBU00069 void encenderEmisora() {
AAAAAAABBWAAAAAAABBW00070 (*this).laEmisora.encenderEmisora();
AAAAAAABBXAAAAAAABBX00071 }
AAAAAAABBYAAAAAAABBY00072
AAAAAAABBZAAAAAAABBZ00073 /**
AAAAAAABCAAAAAAAABCA00074 * @brief Publica una medición de CO2.
AAAAAAABCBAAAAAAABCB00075 * @param valorCO2 Valor de la medición a enviar (se coloca en el campo Minor).
AAAAAAABCCAAAAAAABCC00076 * @param contador Valor incremental para diferenciar anuncios.
AAAAAAABCDAAAAAAABCD00077 * @param tiempoEspera Milisegundos que estará activo el anuncio antes de detenerse.
AAAAAAABCEAAAAAAABCE00078 * @details El campo 'Major' se forma combinando el ID del CO2 (8 bits altos) y el contador (8 bits bajos).
AAAAAAABCFAAAAAAABCF00079 */
AAAAAAABCGAAAAAAABCG00080 void publicarCO2( int16_t valorCO2, uint8_t contador,
AAAAAAABCIAAAAAAABCI00081 long tiempoEspera ) {
AAAAAAABCJAAAAAAABCJ00082
AAAAAAABCKAAAAAAABCK00083 // 1. Calculamos el campo Major (ID + Contador)
AAAAAAABCLAAAAAAABCL00084 uint16_t major = (MedicionesID::CO2 << 8) + contador;
AAAAAAABCMAAAAAAABCM00085
AAAAAAABCNAAAAAAABCN00086 // 2. Emitimos el anuncio iBeacon
AAAAAAABCOAAAAAAABCO00087 (*this).laEmisora.emitirAnuncioIBeacon( (*this).beaconUUID,
AAAAAAABCPAAAAAAABCP00088 major,
AAAAAAABCQAAAAAAABCQ00089 valorCO2, // Minor
AAAAAAABCRAAAAAAABCR00090 (*this).RSSI
AAAAAAABCSAAAAAAABCS00091 );
AAAAAAABCTAAAAAAABCT00092
AAAAAAABCUAAAAAAABCU00093 // 3. Esperamos y detenemos
AAAAAAABCVAAAAAAABCV00094 esperar( tiempoEspera );
AAAAAAABCWAAAAAAABCW00095 (*this).laEmisora.detenerAnuncio();
AAAAAAABCXAAAAAAABCX00096 }
AAAAAAABCYAAAAAAABCY00097
AAAAAAABCZAAAAAAABCZ00098 /**
AAAAAAABDAAAAAAAABDA00099 * @brief Publica una medición de Temperatura.
AAAAAAABDBAAAAAAABDB00100 * @param valorTemperatura Valor térmico (se coloca en el campo Minor).
AAAAAAABDCAAAAAAABDC00101 * @param contador Valor incremental.
AAAAAAABDDAAAAAAABDD00102 * @param tiempoEspera Duración del anuncio en milisegundos.
AAAAAAABDEAAAAAAABDE00103 */
AAAAAAABDFAAAAAAABDF00104 void publicarTemperatura( int16_t valorTemperatura,
AAAAAAABDHAAAAAAABDH00105 uint8_t contador, long tiempoEspera ) {
AAAAAAABDIAAAAAAABDI00106
AAAAAAABDJAAAAAAABDJ00107 uint16_t major = (MedicionesID::TEMPERATURA << 8) + contador;
AAAAAAABDKAAAAAAABDK00108
AAAAAAABDLAAAAAAABDL00109 (*this).laEmisora.emitirAnuncioIBeacon( (*this).beaconUUID,
AAAAAAABDMAAAAAAABDM00110 major,
AAAAAAABDNAAAAAAABDN00111 valorTemperatura, // Minor
AAAAAAABDOAAAAAAABDO00112 (*this).RSSI
AAAAAAABDPAAAAAAABDP00113 );
AAAAAAABDQAAAAAAABDQ00114
AAAAAAABDRAAAAAAABDR00115 esperar( tiempoEspera );
AAAAAAABDSAAAAAAABDS00116 (*this).laEmisora.detenerAnuncio();
AAAAAAABDTAAAAAAABDT00117 }
AAAAAAABDUAAAAAAABDU00118
AAAAAAABDVAAAAAAABDV00119 }; // class
AAAAAAABDWAAAAAAABDW00120
AAAAAAABDXAAAAAAABDX00121 #endif

src/HolaMundoIBeacon/PuertoSerie.h File Reference
AAAAAAABDZAAAAAAABDZ
Clase para gestionar la comunicación serie del microcontrolador.
Classes
class PuertoSerieClase de abstracción para la comunicación serie.

Detailed Description
Clase para gestionar la comunicación serie del microcontrolador.

Author
Rocio
Date
11/11/2025
Proporciona una interfaz simplificada para el uso del objeto Serial de Arduino, permitiendo inicializar la comunicación y escribir diversos tipos de datos.
Definition in file PuertoSerie.h.

PuertoSerie.h
AAAAAAABDYAAAAAAABDYGo to the documentation of this file.

AAAAAAABEAAAAAAAABEA00001 /**
AAAAAAABEBAAAAAAABEB00002 * @file PuertoSerie.h
AAAAAAABECAAAAAAABEC00003 * @brief Clase para gestionar la comunicación serie del microcontrolador.
AAAAAAABEDAAAAAAABED00004 * @author Rocio
AAAAAAABEEAAAAAAABEE00005 * @date 11/11/2025
AAAAAAABEFAAAAAAABEF00006 * @details Proporciona una interfaz simplificada para el uso del objeto Serial
AAAAAAABEGAAAAAAABEG00007 * de Arduino, permitiendo inicializar la comunicación y escribir diversos tipos de datos.
AAAAAAABEHAAAAAAABEH00008 */
AAAAAAABEIAAAAAAABEI00009
AAAAAAABEJAAAAAAABEJ00010 #ifndef PUERTO_SERIE_H_INCLUIDO
AAAAAAABEKAAAAAAABEK00011 #define PUERTO_SERIE_H_INCLUIDO
AAAAAAABELAAAAAAABEL00012
AAAAAAABEMAAAAAAABEM00013 /**
AAAAAAABENAAAAAAABEN00014 * @class PuertoSerie
AAAAAAABEOAAAAAAABEO00015 * @brief Clase de abstracción para la comunicación serie.
AAAAAAABEPAAAAAAABEP00016 * * Facilita la inicialización del puerto y permite enviar mensajes de forma genérica
AAAAAAABEQAAAAAAABEQ00017 * mediante el uso de plantillas (templates).
AAAAAAABERAAAAAAABER00018 */
AAAAAAABESAAAAAAABES00019 class PuertoSerie {
AAAAAAABEVAAAAAAABEV00020
AAAAAAABEWAAAAAAABEW00021 public:
AAAAAAABEXAAAAAAABEX00022
AAAAAAABEYAAAAAAABEY00023 /**
AAAAAAABEZAAAAAAABEZ00024 * @brief Constructor de la clase PuertoSerie.
AAAAAAABFAAAAAAAABFA00025 * @param baudios Velocidad de transmisión en bits por segundo (ej. 9600, 115200).
AAAAAAABFBAAAAAAABFB00026 * @details Inicia la comunicación serie con la velocidad especificada.
AAAAAAABFCAAAAAAABFC00027 */
AAAAAAABFDAAAAAAABFD00028 PuertoSerie (long baudios) {
AAAAAAABFEAAAAAAABFE00029 Serial.begin( baudios );
AAAAAAABFFAAAAAAABFF00030 }
AAAAAAABFGAAAAAAABFG00031
AAAAAAABFHAAAAAAABFH00032 /**
AAAAAAABFIAAAAAAABFI00033 * @brief Bloquea la ejecución hasta que el puerto serie esté listo.
AAAAAAABFJAAAAAAABFJ00034 * @details Es útil en placas con USB nativo donde la conexión serie puede tardar
AAAAAAABFKAAAAAAABFK00035 * unos milisegundos en establecerse tras el arranque.
AAAAAAABFLAAAAAAABFL00036 */
AAAAAAABFMAAAAAAABFM00037 void esperarDisponible() {
AAAAAAABFOAAAAAAABFO00038 while ( !Serial ) {
AAAAAAABFPAAAAAAABFP00039 delay(10);
AAAAAAABFQAAAAAAABFQ00040 }
AAAAAAABFRAAAAAAABFR00041 }
AAAAAAABFSAAAAAAABFS00042
AAAAAAABFTAAAAAAABFT00043 /**
AAAAAAABFUAAAAAAABFU00044 * @brief Escribe un mensaje de cualquier tipo en el puerto serie.
AAAAAAABFVAAAAAAABFV00045 * @tparam T Tipo de dato del mensaje (int, float, char*, etc.).
AAAAAAABFWAAAAAAABFW00046 * @param mensaje El valor o cadena a enviar.
AAAAAAABFXAAAAAAABFX00047 * @details Utiliza una plantilla para delegar la gestión del tipo al método Serial.print() de Arduino.
AAAAAAABFYAAAAAAABFY00048 */
AAAAAAABFZAAAAAAABFZ00049 template<typename T>
AAAAAAABGAAAAAAAABGA00050 void escribir (T mensaje) {
AAAAAAABGCAAAAAAABGC00051 Serial.print( mensaje );
AAAAAAABGDAAAAAAABGD00052 }
AAAAAAABGEAAAAAAABGE00053
AAAAAAABGFAAAAAAABGF00054 }; // class PuertoSerie
AAAAAAABGGAAAAAAABGG00055
AAAAAAABGHAAAAAAABGH00056 #endif

src/HolaMundoIBeacon/ServicioEnEmisora.h File Reference
AAAAAAAAANAAAAAAAAAN
Gestión de Servicios y Características GATT para BLE.
#include <vector>

Classes
class ServicioEnEmisoraClase que representa un Servicio GATT de Bluetooth.
class ServicioEnEmisora::CaracteristicaRepresenta una Característica GATT dentro de un servicio.
Functions
template<typename T> T * alReves (T *p, int n)
Invierte el orden de los elementos en un array.

uint8_t * stringAUint8AlReves (const char *pString, uint8_t *pUint, int tamMax)
Convierte una cadena de texto a un array de uint8_t en orden inverso.

Detailed Description
Gestión de Servicios y Características GATT para BLE.

Author
Rocio
Date
11/11/2025
Este archivo define las clases necesarias para crear un perfil GATT personalizado, permitiendo la lectura, escritura y notificación de datos a través de conexiones Bluetooth.
Definition in file ServicioEnEmisora.h.

AAAAAAABPJAAAAAAABPJFunction Documentation
template<typename T> T * alReves (T * p, int n)
AAAAAAABHHAAAAAAABHH
Invierte el orden de los elementos en un array.

Template Parameters
T | Tipo de los elementos del array.
Parameters p | Puntero al array.
n | Número de elementos.
Returns Puntero al array modificado.
Definition at line 24 of file ServicioEnEmisora.h.
uint8_t * stringAUint8AlReves (const char * pString, uint8_t * pUint, int tamMax)
AAAAAAABIAAAAAAAABIA
Convierte una cadena de texto a un array de uint8_t en orden inverso.
Útil para convertir strings de UUID a formato Little Endian requerido por la pila BLE.
Parameters
pString | Cadena de origen (C-string).
pUint | Puntero al array de destino.
tamMax | Tamaño máximo a copiar (normalmente 16 para UUIDs).
Returns Puntero al array de destino.
Definition at line 42 of file ServicioEnEmisora.h.

ServicioEnEmisora.h
AAAAAAABGIAAAAAAABGIGo to the documentation of this file.

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

Index
INDEX

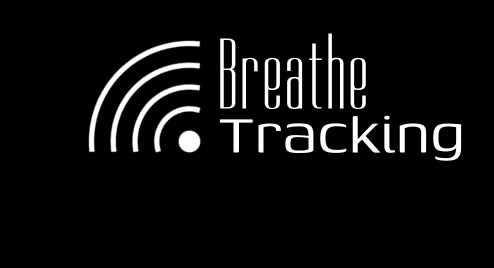
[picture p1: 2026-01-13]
docs/rtf/Imagen de WhatsApp 2025-10-30 a las 19.29.43_719a80ef.jpg

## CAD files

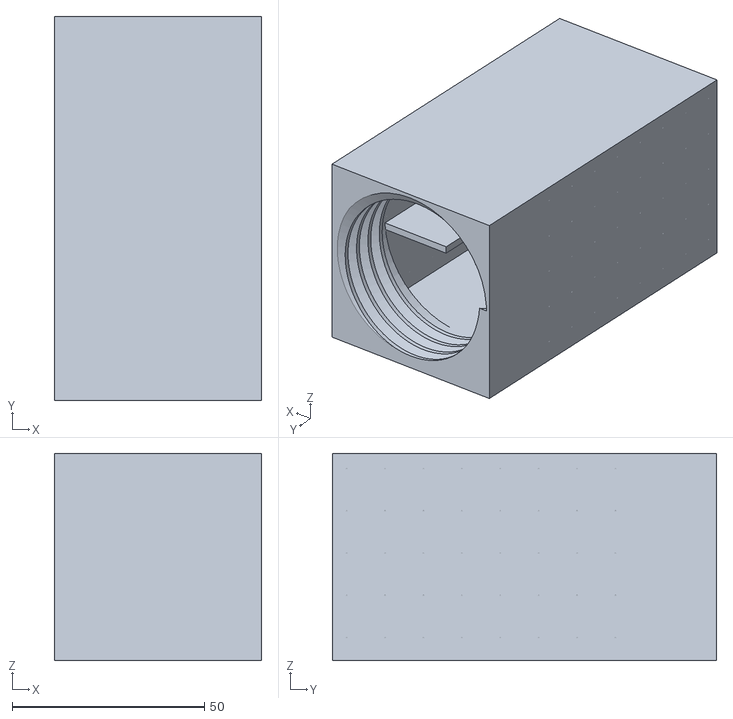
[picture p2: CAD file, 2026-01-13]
GTI_Caja_ROSCANORMAL_00_VFINAL.STL
54.0 x 100.0 x 54.0

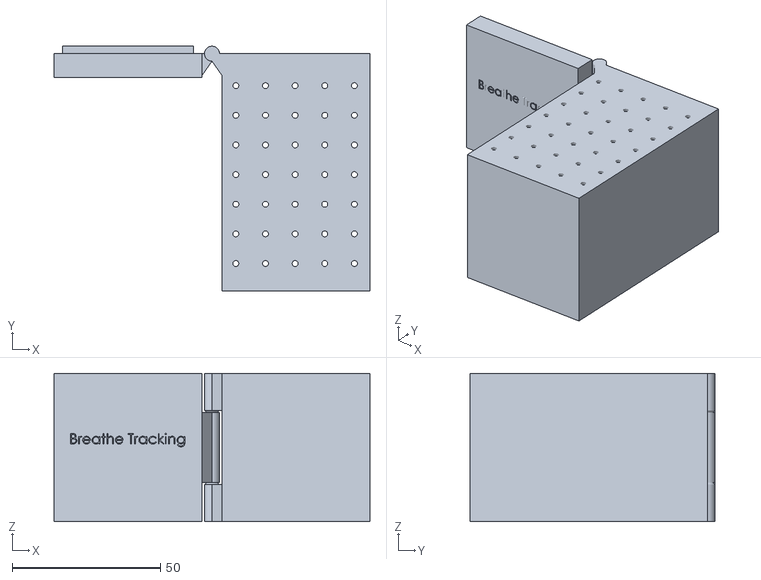
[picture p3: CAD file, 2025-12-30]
src/Caja_proyectoGTI_FINALCONTAPA.STL
106.6 x 82.5 x 50.0

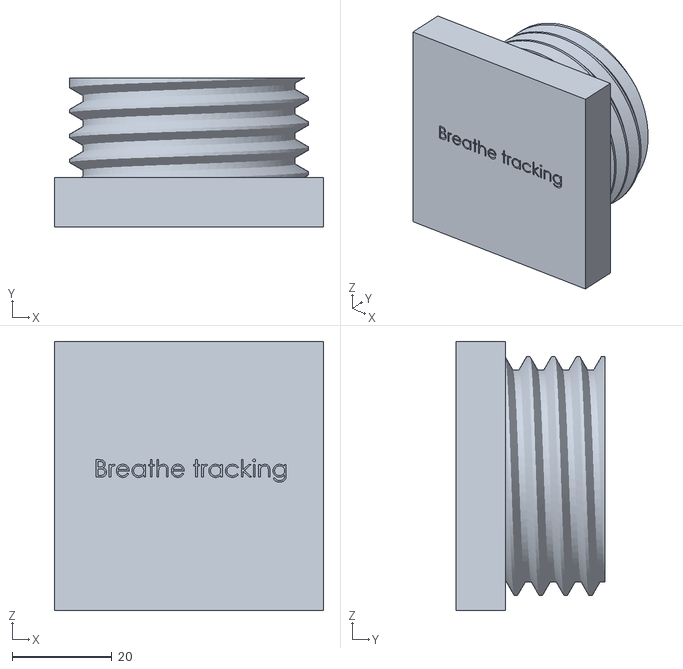
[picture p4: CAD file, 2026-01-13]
Caja_proyectoGTI_004_VS02_TAPONROSCAconnombre_M48P5.STL
54.0 x 30.0 x 54.0

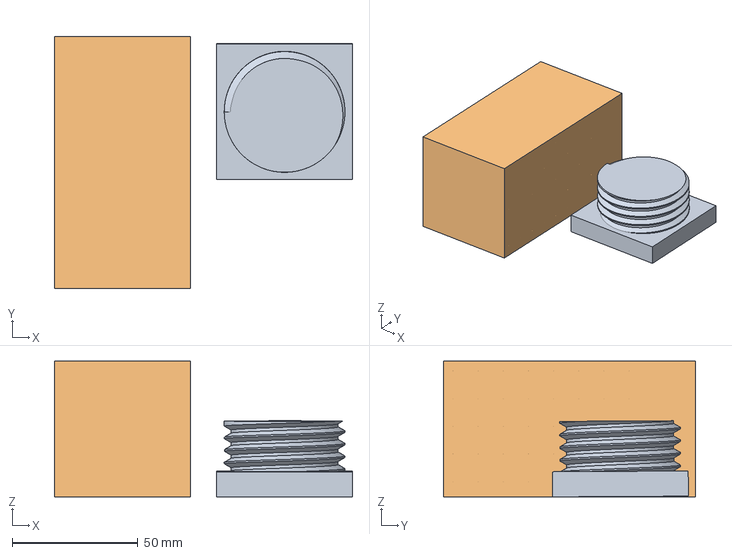
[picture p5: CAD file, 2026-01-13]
GTI_CajaVFINAL.3mf
118.5 x 100.0 x 54.0 mm
Caja_proyectoGTI_004_VS02_TAPONROSCAconnombre_M48P5.STL
GTI_Caja_ROSCAAJUSTADA_00_VFINAL.STL

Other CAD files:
GTI_Caja_ROSCAAJUSTADA_00_VFINAL.STL

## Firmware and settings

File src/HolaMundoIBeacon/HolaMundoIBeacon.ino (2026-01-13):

// --------------------------------------------------------------
/**
 * @file HolaMundoIBeacon.ino
 * @brief Sistema de monitorización ambiental (O3, CO2, Temperatura) con tecnología BLE.
 * @author Rocio
 * @date 11/11/2025
 * @details 
 * **Historial de cambios:**
 * - 26/11/25: Implementación de lectura de sensores y gestión de batería.
 * - 09/01/26: Adaptación completa de comentarios para generación con Doxygen.
 * * Este programa gestiona la adquisición de datos de sensores de gas (Ozono), 
 * niveles de CO2, temperatura y estado de carga de batería, emitiendo dicha 
 * información mediante anuncios Bluetooth Low Energy (Beacons personalizados).
 */
// --------------------------------------------------------------

#include <bluefruit.h>

// Evitar conflictos con macros de Arduino
#undef min 
#undef max 

#include "LED.h"
#include "PuertoSerie.h"

/**
 * @namespace Globales
 * @brief Espacio de nombres para objetos con persistencia global.
 * @details Contiene las instancias de hardware y servicios compartidos por todo el sistema.
 */
namespace Globales {
  /// Instancia para el control del LED de estado (conectado al pin 7).
  LED elLED (7);

  /// Instancia para la comunicación serie (configurada a 115200 baudios).
  PuertoSerie elPuerto (115200); 
}

#include "EmisoraBLE.h"
#include "Publicador.h"
#include "Medidor.h"

namespace Globales {
  /// Objeto encargado de gestionar la emisión de anuncios BLE.
  Publicador elPublicador;

  /// Objeto encargado de realizar las mediciones de los sensores analógicos y digitales.
  Medidor elMedidor;
}

/**
 * @brief Configura los pines de entrada analógica.
 * @details Establece los modos de pin para la lectura del sensor de Ozono 
 * (VGAS y VREF) y el divisor de tensión de la batería.
 */
void inicializarPlaquita () {
  pinMode(O3_PIN_VGAS, INPUT); // A5 por defecto
  pinMode(O3_PIN_VREF, INPUT); // A4 por defecto
  pinMode(PIN_A6, INPUT);      // Pin de monitorización de Batería
}

/**
 * @brief Función de configuración inicial (Arduino Setup).
 * @details Inicializa periféricos, establece la semilla aleatoria para simulaciones,
 * arranca la emisora BLE y realiza la calibración inicial del sensor de gas.
 */
void setup() {
  // Inicialización de hardware
  inicializarPlaquita(); 

  // Semilla para valores aleatorios (usada en mediciones simuladas)
  randomSeed(analogRead(0)); 

  // Activación del servicio BLE
  Globales::elPublicador.encenderEmisora();

  // Inicialización y calibración del medidor de gas
  Globales::elMedidor.iniciarMedidor();
  esperar( 1000 );

  float vref_calibrado = Globales::elMedidor.getVrefBase();  
  Globales::elPuerto.escribir( "Vref Calibracion (V): " );
  Globales::elPuerto.escribir( vref_calibrado ); 
  Globales::elPuerto.escribir( "\n" );
  
  esperar( 1000 );
  Globales::elPuerto.escribir( "---- setup(): fin ---- \n " );
}

/**
 * @brief Ejecuta una secuencia visual de parpadeo.
 * @details Realiza una serie de encendidos y apagados del LED para indicar que 
 * el dispositivo está procesando un nuevo ciclo de medida.
 */
inline void lucecitas() {
  using namespace Globales;
  elLED.brillar( 100 ); esperar ( 400 ); 
  elLED.brillar( 100 ); esperar ( 400 ); 
  elLED.brillar( 100 ); esperar ( 400 ); 
  elLED.brillar( 1000 ); esperar ( 1000 ); 
}

/**
 * @namespace Loop
 * @brief Variables persistentes relativas al ciclo de vida del loop.
 */
namespace Loop {
  uint8_t cont = 0; ///< Contador incremental de ciclos de medición.
}

/**
 * @brief Bucle principal de ejecución (Arduino Loop).
 * @details Realiza las siguientes acciones:
 * 1. Lee los sensores (O3, CO2, Temp, Batería).
 * 2. Empaqueta los datos en un array de 9 bytes (Little Endian).
 * 3. Emite la información mediante un anuncio BLE durante 30 segundos.
 * * **Estructura del Payload (9 bytes):**
 * | Byte 0 | Bytes 1-2 | Bytes 3-4 | Bytes 5-6 | Bytes 7-8 |
 * |:------:|:---------:|:---------:|:---------:|:---------:|
 * | ID(0xAA)| O3 (ppb)  | Temp (x10)| CO2 (ppm) | Bat (%)   |
 */
void loop () {
  using namespace Loop;
  using namespace Globales;

  cont++;
  elPuerto.escribir( "\n---- loop(): empieza " );
  elPuerto.escribir( cont );
  elPuerto.escribir( "\n" );

  lucecitas();

  // --- Adquisición de Medidas ---
  float valorO3 = elMedidor.medirPPM(); 
  int valorCO2 = elMedidor.medirCO2();
  int valorTemperatura = elMedidor.medirTemperatura();
  int valorBateria = elMedidor.medirBateria();

  // Mostrar datos por puerto serie para depuración
  elPuerto.escribir( "O3 (ppm): " );
  elPuerto.escribir( valorO3); 
  elPuerto.escribir( "\n" );
  
  // --- Empaquetado de Datos ---
  // O3 se guarda en ppb (partes por billón) multiplicando ppm por 1000
  uint16_t O3_pack = (uint16_t)(valorO3 * 1000.0f); 
  uint16_t Temp_pack = (uint16_t)valorTemperatura; 
  uint16_t CO2_pack = (uint16_t)valorCO2; 
  uint16_t Bat_pack = (uint16_t)valorBateria;

  uint8_t datos_payload[9] = {0};
  datos_payload[0] = 0xAA; // Cabecera identificadora del protocolo

  // Empaquetado Little Endian (Byte bajo primero)
  datos_payload[1] = (uint8_t)(O3_pack & 0xFF);
  datos_payload[2] = (uint8_t)(O3_pack >> 8);

  datos_payload[3] = (uint8_t)(Temp_pack & 0xFF);
  datos_payload[4] = (uint8_t)(Temp_pack >> 8);

  datos_payload[5] = (uint8_t)(CO2_pack & 0xFF);
  datos_payload[6] = (uint8_t)(CO2_pack >> 8);

  datos_payload[7] = (uint8_t)(Bat_pack & 0xFF);
  datos_payload[8] = (uint8_t)(Bat_pack >> 8);

  // --- Emisión BLE ---
  elPublicador.laEmisora.emitirDatosMultiples(datos_payload, sizeof(datos_payload));
  
  esperar( 30000 ); // Mantener el anuncio activo 30 segundos

  elPublicador.laEmisora.detenerAnuncio();

  elPuerto.escribir( "---- loop(): acaba **** " );
  elPuerto.escribir( cont );
  elPuerto.escribir( "\n" );
  
} // loop ()

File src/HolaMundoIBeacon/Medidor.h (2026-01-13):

/**
 * @file Medidor.h
 * @brief Clase para la gestión de sensores analógicos y simulados.
 * @author Rocio
 * @date 11/11/2025
 * @details Este archivo contiene la lógica para calcular concentraciones de O3 
 * mediante un sensor electroquímico, así como la estimación del nivel de batería
 * y la generación de datos simulados para CO2 y Temperatura.
 */

#ifndef MEDIDOR_H_INCLUIDO
#define MEDIDOR_H_INCLUIDO

#include <Arduino.h>
#include <math.h>

// ===================== CONSTANTES DE CONFIGURACIÓN (O3) =====================

#ifndef O3_PIN_VGAS
#define O3_PIN_VGAS A5 ///< Pin para el voltaje de gas del sensor de ozono.
#endif
#ifndef O3_PIN_VREF
#define O3_PIN_VREF A4 ///< Pin para el voltaje de referencia del sensor de ozono.
#endif

#ifndef O3_VDD
#define O3_VDD 1.20f      ///< Voltaje de alimentación del sensor/ADC (V).
#endif

#ifndef O3_ADC_BITS
#define O3_ADC_BITS 12      ///< Resolución del ADC para ozono (12 bits).
#endif

/** @brief Sensibilidad del sensor electroquímico en nA/ppm. */
const float SENSIBILIDAD_SENSOR = -44.26f;  
/** @brief Resistencia de ganancia del amplificador de transimpedancia (TIA) en Ohmios. */
const float GAIN_TIA = 499.0f;    

// ===================== CONSTANTES DE CORRECCIÓN =====================

const float CORRECCION_SLOPE = 1.0f;  ///< Factor de escala para ajuste de ganancia (m').
const float CORRECCION_OFFSET = 0.0f; ///< Desplazamiento para ajuste de línea base (b').

// ===================== DATOS SIMULADOS =====================

/// @brief Array de valores de Ozono simulados (ppm * 1000).
const int O3_SIMULADO[] = {100, 650, 45, 1200, 950, 800, 300}; 
const int NUM_O3_VALORES = sizeof(O3_SIMULADO) / sizeof(O3_SIMULADO[0]);

/// @brief Array de valores de CO2 simulados (ppm).
  //const int CO2_SIMULADO[] = {400, 550, 850, 1000, 1250, 1300, 950};
const int CO2_SIMULADO[] = {1400, 1350, 1360, 1280, 1250, 1300, 1450};
const int NUM_CO2_VALORES = sizeof(CO2_SIMULADO) / sizeof(CO2_SIMULADO[0]);

/// @brief Array de temperaturas simuladas (ºC * 10).
  //const int TEMP_SIMULADA[] = {220, 245, 266, 289, 235, 68, 353, 360, 400, 320};
const int TEMP_SIMULADA[] = {320, 345, 366, 389, 335, 368, 353, 360, 400, 320};
const int NUM_TEMP_VALORES = sizeof(TEMP_SIMULADA) / sizeof(TEMP_SIMULADA[0]);

/// @brief Array de porcentajes de batería simulados.
  //const int BAT_SIMULADA[] = {98, 87, 80, 75, 50, 30, 15, 77, 63}; 
const int BAT_SIMULADA[] = {15, 14, 12, 10, 8, 7, 3, 1}; 
const int NUM_BAT_VALORES = sizeof(BAT_SIMULADA) / sizeof(BAT_SIMULADA[0]);

// ===================== CONSTANTES BATERÍA REAL =====================

const float BATT_MAX_VOLTS = 4.20f; ///< Voltaje LiPo al 100%.
const float BATT_MIN_VOLTS = 3.30f; ///< Voltaje LiPo al 0%.
const float VDD = 3.30f;            ///< Referencia de voltaje del sistema (V).
const int ADC_BITS = 10;            ///< Resolución ADC para batería.

/**
 * @class Medidor
 * @brief Se encarga de la adquisición y procesamiento de datos ambientales.
 * * Esta clase encapsula tanto las lecturas de los pines analógicos como
 * el procesamiento matemático para convertir voltajes en unidades físicas.
 */
class Medidor {

private:
  float _Vref_base = 0.0f; ///< Valor de calibración inicial de VREF.

  /**
   * @brief Lee el voltaje de un pin analógico promediando varias muestras.
   * @param pin Pin analógico a leer.
   * @param nAvg Número de muestras para el promedio.
   * @return Voltaje calculado en Voltios.
   */
  float leerVolt(int pin, int nAvg = 10) {
    long acc = 0;
    for (int i=0; i<nAvg; ++i) { acc += analogRead(pin); delay(2); }
    const float raw = (float)acc / nAvg;
    const float fullScale = (float)((1 << O3_ADC_BITS) - 1); 
    return (raw * O3_VDD) / fullScale;
  }

public:

  /**
   * @brief Constructor por defecto.
   */
  Medidor(  ) {
  }

  /**
   * @brief Calibra el medidor obteniendo el voltaje de referencia inicial.
   * @param nAvg Número de muestras para la calibración (por defecto 50).
   */
  void iniciarMedidor(int nAvg = 50) {
       _Vref_base = leerVolt(O3_PIN_VREF, nAvg);
  }
  
  /**
   * @brief Calcula el porcentaje de carga de la batería real.
   * @details Utiliza un divisor de tensión 2:1 en el pin A6.
   * @return Porcentaje de batería (0-100).
   */
  int medirBateria() {
      const int nAvg = 10;
      long rawAcc = 0;
      for (int i = 0; i < nAvg; ++i) { 
          rawAcc += analogRead(PIN_A6); 
          delay(1); 
      }
      const float rawAvg = (float)rawAcc / nAvg;
      const float fullScale = (float)((1 << ADC_BITS) - 1); 
      float measuredVolts = (rawAvg * VDD) / fullScale;
      
      // Multiplicar por 2 por el divisor de voltaje del hardware
      float battVolts = measuredVolts * 2.0f; 
      
      float battRange = BATT_MAX_VOLTS - BATT_MIN_VOLTS;
      float percent = ((battVolts - BATT_MIN_VOLTS) / battRange) * 100.0f;

      if (percent > 100.0f) percent = 100.0f;
      if (percent < 0.0f) percent = 0.0f;

      return (int)percent;
  }

  /**
   * @brief Obtiene una medida de CO2 de los datos simulados.
   * @return Valor de CO2 en ppm.
   */
  int medirCO2() {
    int indiceAleatorio = random(0, NUM_CO2_VALORES); 
    return CO2_SIMULADO[indiceAleatorio];
  }

  /**
   * @brief Obtiene una medida de temperatura de los datos simulados.
   * @return Temperatura (ºC * 10).
   */
  int medirTemperatura() {
    int indiceAleatorio = random(0, NUM_TEMP_VALORES);
    return TEMP_SIMULADA[indiceAleatorio];
  }
  
  /**
   * @brief Retorna el voltaje de referencia base calibrado al inicio.
   * @return Voltaje en Voltios.
   */
  float getVrefBase() const {
        return _Vref_base; 
  }

  /**
   * @brief Lee el voltaje actual en el pin Vgas del sensor de O3.
   * @param nAvg Número de muestras para el promedio.
   * @return Voltaje en Voltios.
   */
  float leerVgas(int nAvg = 10) { 
        return leerVolt(O3_PIN_VGAS, nAvg); 
  }

  /**
   * @brief Obtiene una medida de Ozono de los datos simulados.
   * @return Valor de ozono en ppm (float).
   */
  float medirPPMSimulado() {
    int indiceAleatorio = random(0, NUM_O3_VALORES);
    float valorSimuladoRaw = (float)O3_SIMULADO[indiceAleatorio];      
    return valorSimuladoRaw / 1000.0f;
  }

  /**
   * @brief Realiza la medición real de Ozono (O3) en ppm.
   * @details Calcula la diferencia entre Vgas y Vref, convierte a corriente y 
   * aplica las constantes de sensibilidad y corrección (slope/offset).
   * @return Concentración de ozono corregida en ppm.
   */
  float medirPPM() {
    float Vg = leerVolt(O3_PIN_VGAS, 10);
    float deltaV = Vg - _Vref_base;
        
    float denominador = GAIN_TIA * SENSIBILIDAD_SENSOR * 1e-6f; 
        
    float ppm_bruto = 0.0f;
    if (denominador != 0.0f) {
      ppm_bruto = deltaV / denominador;
    }

    ppm_bruto = fabsf(ppm_bruto); 
        
    // Ajuste lineal final
    float ppm_corregido = (ppm_bruto * CORRECCION_SLOPE) + CORRECCION_OFFSET;

    if (ppm_corregido < 0.0f) {
      ppm_corregido = 0.0f;
    }
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

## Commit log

2025-11-11 Base Arduino
2025-11-11 Revert "Base Arduino"
    This reverts commit ec4cc67a8adec03141a119bc78226d063663780c.
2025-11-11 Update de clase Medidor
    Fusion de Medidor y MedidorO3
2025-11-26 Detección nivel de batería
    El pin A6 registra el nivel de voltaje y lo convierte a porcentaje de bateria para eliminar el valor simulado
2025-12-30 Primera versión caja proyecto
    [Caja_proyectoGTI_FINALCONTAPA.STL]
2026-01-13 Diseño caja con tapón con rosca
    [Caja_proyectoGTI_004_VS02_TAPONROSCAconnombre_M48P5.STL, Caja_proyectoGTI_FINALCONTAPA.STL, GTI_CajaVFINAL.3mf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]
